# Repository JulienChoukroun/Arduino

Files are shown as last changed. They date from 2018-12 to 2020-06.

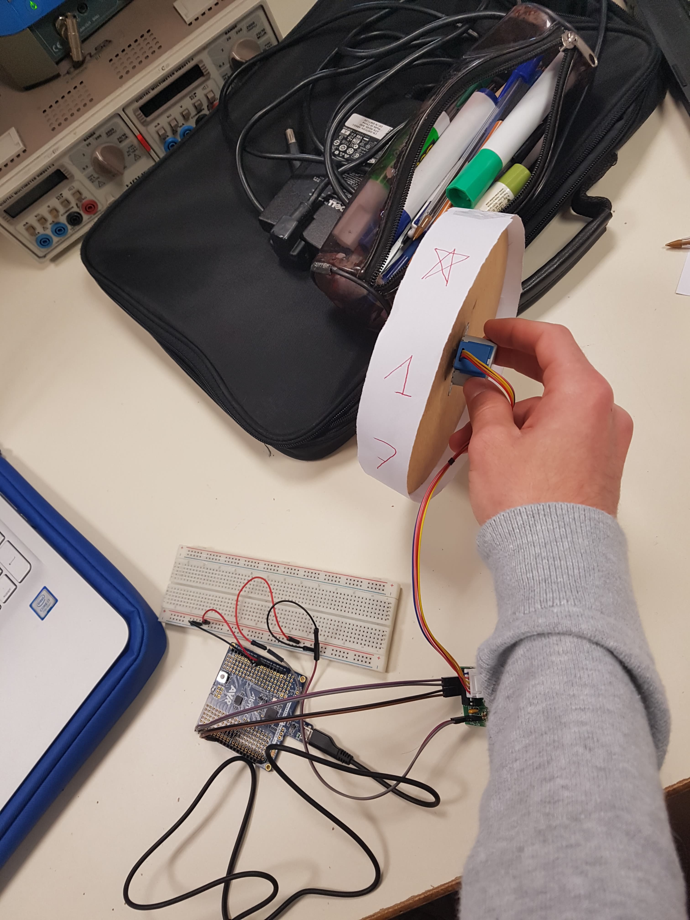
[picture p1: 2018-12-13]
Documentation/Roue/testRoueEnBoisMoteurPasAPas.jpg

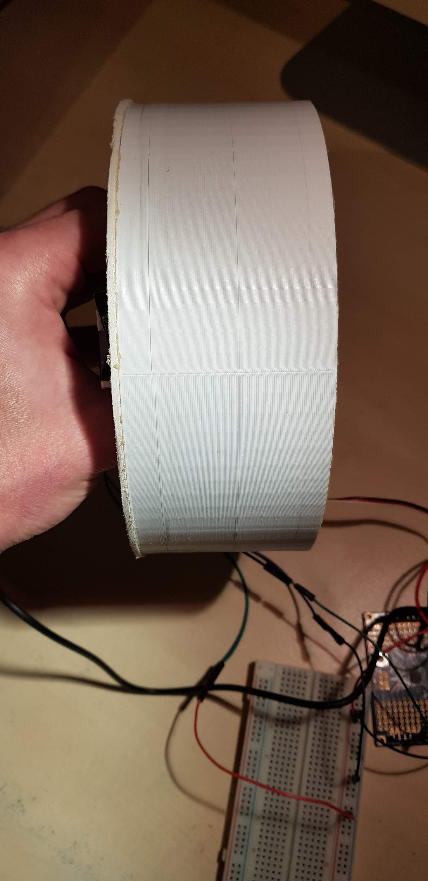
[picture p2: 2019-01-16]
Documentation/Roue/roueAssembléeFace.jpg

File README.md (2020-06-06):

Ce projet est réalisé dans le cadre de la formation de prépa intégrée (deuxième année) de l'Ecole Polytechnique de l'Université Côte d'Azur.
***
# Machine à sous connectée
Machine A Sous
## Présentation
Ce projet a été réalisé avec une carte Arduino Uno.

Nous avons conçu cette machine à sous de A à Z.

Le principe est d'insérer une pièce dans la machine. A ce moment-là, une initialisation va s'effectuer.
Puis, le joueur appuie sur le bouton. Les roues vont alors s'actionnner et s'arrêter aléatoirement. Pour gagner, il faut aligner 3 symboles identiques. 

Liens vidéos finales :

Vidéos aléatoire :
https://www.youtube.com/watch?v=_GDTUbmNEMA

Vidéos jackpot :
https://www.youtube.com/watch?v=zs_Bld9j-1k

https://www.youtube.com/watch?v=MiqmttVf-DY

https://www.youtube.com/watch?v=LnEOkYjUT1s

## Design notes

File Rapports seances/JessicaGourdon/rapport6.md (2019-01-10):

# Séance du 10 Janvier
Aujourd'hui, nous avons trouvé une petite planche en bois fine de 3mm que l'on a fixé au servomoteur. Nous avons ensuite réalisé quelques tests pour observer la rotation de ce dispositif.
Nous avons donc modifier le code du monnayeur. Le nouveau est le suivant: https://github.com/JessicaJulien/projet/blob/master/Codes/monnayeur1.ino
Par la suite nous avons réflechi aux dimensions à prendre pour réaliser les jetons ainsi que l'écart à laisser entre le socle et le cylindre.
Nous avons donc décidé de prendre une épaisseur de 4 mm pour les jetons. Ainsi, nous laissons un écart de 5 mm entre le socle et le cylindre( 1 mm en plus pour éviter tout frottement).
Le schéma du monnayeur est donc le suivant:

<strong> Problème de la roue </strong> <br/>
Nous rencontrons un problème par rapport à la détection de la position initiale de la roue.
Dans un premier temps, nous avons pensé à mettre une petite fente au niveau de chaque autocollant sur la roue et une grande fente à l'endroit où l'on souhaitera que la roue commence à tourner ( la position initiale).
La première fois, la roue tournera lentement pour détecter la position initiale. Une fois la grande fente détectée, la roue s'arrête au niveau de cette position initiale. Ensuite, on fait tourner la roue à sa vitesse normale pendant un certain nombre de secondes tout en comptant le nombre de fentes rencontrées pour pouvoir se repérer.
Puis nous nous sommes rendus compte qu'il serait plus simple de ne réaliser qu'une seule fente, située à la position initiale. Par la suite, grâce à la précision de la vitesse du moteur et à l'aide d'un calcul, nous serons en mesure de connaître la position finale du détecteur.

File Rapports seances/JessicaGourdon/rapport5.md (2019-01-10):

# Travail du 9 Janvier 2019
En réflechissant encore au fonctionnement du monnayeur, je me suis rendue compte que le tube de Smarties, lui non plus, n'était pas assez rigide
pour faire office de cylindre. En effet, étant en carton très fin, il m'aurait fallu le fixer sur le socle en bois avec une tige (en fer ou en bois)
pour le maintenir droit et éviter qu'il ne tombe. J'ai finalement décider de me servir d'un tuyau en PVC qui sera fixé au socle grâce à une petite
équerre. Cela nous permettra également de le surélever de quelques millimètres pour laisser passer un jeton.

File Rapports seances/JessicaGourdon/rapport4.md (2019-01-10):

# Travail du 8 Janvier 2019

Après réflexion, l'idée d'utiliser un rouleau de papier toilette comme cylindre du monnayeur contenant les pièces présente des inconvénients:
il est trop peu rigide et pas assez long. J'ai donc pensé à le remplacer par un gros tube de Smarties.
J'ai réalisé un premier code pour contrôler le servomoteur du monnayeur. Celui-ci est le suivant:
https://github.com/JessicaJulien/projet/blob/master/Codes/premierProgrammeMonnayeur.ino
Le servomoteur, auquel sera fixé une petite plaque de bois, réalisera donc une rotation de 90° de manière à éjecter chaque pièce sortant du cylindre.
Ici, le code a été créé pour éjecter 5 pièces. A l'avenir le nombre de jetons renvoyés dépendra de la valeur indiquée par les roues
(en effet, un 7 nous fera gagner plus de jetons qu'une cerise).

<strong> Le Fablab </strong> <br/>
Avec julien nous nous sommes rendus au Fablab dans le but d'utiliser la découpeuse laser et l'imprimante 3D pour créer les composantes de la première roue.
Face à des problèmes de matériaux non-disponibles et de format des fichiers, nous n'avons pu créer que le socle de la roue. Nous devrons donc y retourner pour créer le reste des composantes ainsi que les jetons.

<strong> Problème à l'avenir </strong> <br/>
Il me reste à trouver un moyen pour faire tenir le tube de Smarties sur le socle en bois tout en laissant un écart entre les deux 
de façon à laisser passer une pièce qui sera éjectée par le servomoteur.

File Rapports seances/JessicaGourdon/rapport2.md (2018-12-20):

# Séance du 20 Décembre 2018

<strong> Test du détecteur IR </strong> <br/>
Pour commencer cette séance, je me suis chargé de tester le détecteur FC-03. Pour cela on se sert de ce détecteur ainsi que d'une LED.
Lorsqu'on passe un objet à l'intérieur de la fourche du détecteur, la LED s'allume. Le code utilisé est:
https://github.com/JessicaJulien/projet/blob/master/Codes/DetecteurIR.ino

Pendant ce temps, Julien réalisait les tests du détecteur HC-SRO4.

<strong> Test du Servomoteur à rotation continue  </strong> <br/>
Au vu des résultats de la semaine dernière, puisque la vitesse du moteur pas à pas ne nous satisfaisait pas, nous choisissons de nous servir du Servomoteur à rotation continue. Nous avons testé ce moteur et la vitesse nous convenait cette fois-ci. 

Nous avons également pris une nouvelle décision pour la réalisation des roues. Au lieu de créer les roues a l'imprimante 3D nous nous servirons de cercles en bois auxquels nous fixons autour une bande en plastique.

Nous devons à présent chercher des autocollants convenant avec les dimensions de la bande en plastique. Nous travaillons également sur le système de détection de chaque image sur la bande en plastique.

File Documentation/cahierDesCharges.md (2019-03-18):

# Cahier des charges

* Contexte : réalisation d’une machine à sous contrôlé par une carte Arduino.
* Objectif :  

  - Détection de l’insertion d’une pièce dans la machine.
  - Rotation des roues et affichage des symboles à la fin du jeu.
  - Rendu de la monnaie si le joueur a gagné.
            
* Contraintes : 

  - Utiliser une carte Arduino.
  - Utiliser une connexion radiofréquence.
  - Délai : 9 séances.

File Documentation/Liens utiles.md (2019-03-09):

#### Arduino Fruit Machine - Feature Reel
<a href="https://www.youtube.com/watch?v=QCF7HrBWTgs&t=0s&index=6&list=LLB7UFHfT3-WoMwWvKr9C8wA">Arduino Fruit Machine - Feature Reel</a>

#### DIY! Slot machine How to make a Casino Slot machine from cardboard
<a href="https://www.youtube.com/watch?v=1jY8ld2u5S0">DIY! Slot machine How to make a Casino Slot machine from cardboard</a>

#### Comment fonctionnent les machines à sous ?
https://www.casino-zen.com/fonctionnement-des-machines-a-sous/

#### Moteurs pas à pas
https://www.gotronic.fr/cat-moteurs-pas-a-pas-1093.htm

#### Servomoteur à rotation continue
https://www.parallax.com/product/900-00025

#### Guide de notre servomoteur à rotation continue
https://www.parallax.com/sites/default/files/downloads/900-00025-High-Speed-CR-Servo-Guide-v1.1.pdf

#### Module MP3
https://www.ebay.fr/itm/YX5300-UART-Control-Serial-MP3-Music-Player-Module-for-Arduino-AVR-ARM-PIC/263548780875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

#### Stickers
https://stickeramoi.com/chiffres-et-numeros/6260-sticker-chiffre-7.html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
https://stickeramoi.com/fuits-legumes-rigolos/11917-sticker-ananas.html
https://stickeramoi.com/sticker-trefle/15005-sticker-trefle-4-feuilles-vert.html
https://stickeramoi.com/fuits-legumes-rigolos/11919-sticker-cerise.html
https://stickeramoi.com/sticker-poker/16929-sticker-poker-carreau-rouge.html
https://stickeramoi.com/sticker-poker/16928-sticker-poker-coeur-rouge.html
https://stickeramoi.com/sticker-poker/8169-autocollant-poker-des-jeu-de-casino.html
https://stickeramoi.com/sticker-poker/16926-sticker-poker-pique-noir.html

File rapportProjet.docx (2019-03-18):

Parcours des Ecoles d’Ingénieurs Polytech (PEIP)

PROJET ARDUINO – PEIP2

Année scolaire 2018-2019

″Polytech’ Slot Machine″

Etudiants : Julien Choukroun et Jessica Gourdon

Encadrants : Mr. Masson et Mr. Abderrahmane

Ecole Polytechnique Universitaire de Nice Sophia-Antipolis, PEIP

1645 route des Lucioles, Parc de Sophia Antipolis, 06410 BIOT

REMERCIEMENTS

Avant d’introduire notre sujet et de rentrer dans les détails de celui-ci, nous tenons à remercier Mr. Masson, professeur d’électronique et directeur du PEIP, pour ses conseils et son aide, ainsi que Mr. Forner, Fabmanager du FabLab de Sophia.

SOMMAIRE

# Introduction

L’univers du casino étant un univers nous touchant particulièrement tous les deux, nous avons choisi de réaliser une machine à sous. Objet connu du grand publique, beau esthétiquement, divertissant et ludique, nous avons conçu cette machine de A à Z.

Ce projet se base sur la carte Arduino Uno.

Le principe est d’insérer une pièce dans la machine. A ce moment-là, une initialisation des roues va s’effectuer : elles vont s’arrêter sur les symboles « 7 ». Ensuite, le joueur appuie sur le bouton pour faire tourner les roues. Ces dernières vont s’arrêter aléatoirement sur des symboles.

Pour gagner, il faut aligner trois symboles identiques. Nous avons mis en place 3 jackpots différents : si nous alignons trois « fruits » (ananas et raisin), nous gagnons 5 pièces. Si nous alignons trois « couleurs » (cœur, carreau, pique et trèfle), nous gagnons 10 pièces. Enfin, si nous alignons trois « 7 », nous gagnons 20 pièces.

Pour commencer, nous allons décrire l’objectif de notre projet ainsi que les composants utilisés. Puis, nous allons donner une vision globale du projet avec les différents modules, accompagnés d’un algorithme, c’est-à-dire, l’enchainement des fonctions de notre programme. Nous allons exposer nos plannings (initial et final), avec une comparaison de ce que nous avons finalement fait. Ensuite, nous allons parler des problèmes que nous avons rencontrés et comment nous les avons surmontés. Pour finir, nous allons expliquer ce qui fonctionne, ce qui ne fonctionne pas et ce qu’il faudrait faire par la suite si nous avions eu encore neuf séances supplémentaires.

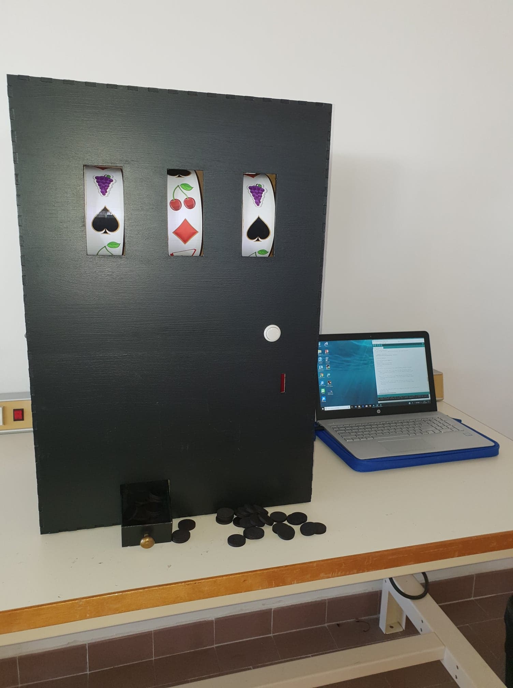
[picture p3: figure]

# Chapitre I : Objectif

## I.1. Cahier des charges

- Contexte : réalisation d’une machine à sous contrôlée par une carte Arduino.
- Objectif : - Détection de l’insertion d’une pièce dans la machine.

- Rotation des roues et affichage des symboles à la fin du jeu.

- Rendu de la monnaie si le joueur a gagné.

- Contraintes : - Utiliser une carte Arduino.

- Utiliser une connexion radiofréquence.

- Délai : 9 séances.

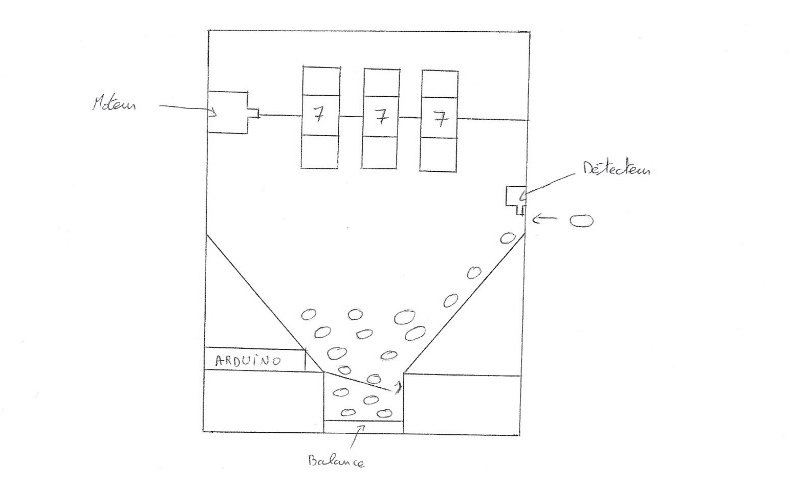
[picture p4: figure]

Figure I.1. Dessin du prototype de machine à sous.

## I.2. Composants utilisés

Pour réaliser la Polytech’ Slot Machine, il nous a fallu de nombreux outils et différents composants.

- Il nous a évidemment fallu utiliser une carte Arduino. Nous avons choisi la carte Arduino Uno.

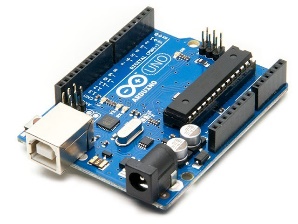
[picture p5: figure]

Figure I.2. Carte Arduino Uno.

- Nous nous sommes également servis de trois servomoteurs à rotation continue pour réaliser les rotations des trois roues. En effet, ceux-ci nous offraient une vitesse de rotation satisfaisante ainsi qu'un bon contrôle de celles-ci.

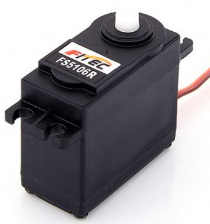
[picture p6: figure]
RÃ©sultat de recherche d'images pour "servomoteur rotation continue arduino"

Figure I.3. Servomoteur à rotation continue.

- Il nous a ensuite fallu un servomoteur à rotation 180° pour réaliser le rendu de la monnaie. En effet, celui-ci nous a permis d’éjecter les pièces, à partir du monnayeur.

Figure I.4. Servomoteur à rotation 180°.

- Puis, nous avons eu besoin de quatre détecteurs Keyes IR-01.

Il s'agit d'un module possédant une diode Infrarouge (IR) ainsi qu'un phototransistor. La détection se réalise grâce à une comparaison de tension. En présence de lumière le phototransistor est passant. La tension de sortie sera égale à 0 V (« 0 » en valeur logique). Il s'agit donc de l'état pour lequel le module ne détecte rien. S'il n'y a pas de lumière, le phototransistor est bloqué. La tension de sortie sera donc égale à 5 V (« 1 » en valeur logique). Il s'agit donc de l'état pour lequel le module détecte quelque chose. Nous avons donc besoin d'une surface noire (qui ne laisse pas passer la lumière) pour la détection.

Nous avons utilisé trois de ces modules pour les roues et le quatrième pour la détection des pièces lors de leur insertion.

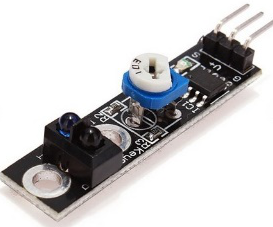
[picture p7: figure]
RÃ©sultat de recherche d'images pour "keyes ir 01 arduino"

Figure I.5. Détecteur Keyes IR-01.

- Nous nous sommes également servis d'un gros bouton poussoir qui déclenchera la rotation des roues.

Figure I.6. Bouton poussoir.

- Nous avons aussi utilisé des bandes de LED pour le système d'éclairage des roues.

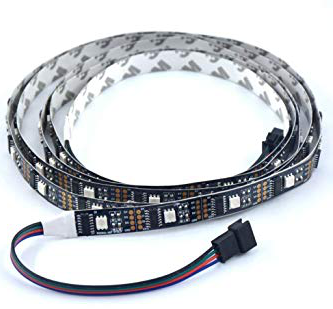
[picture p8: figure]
RÃ©sultat de recherche d'images pour "bande led arduino"

Figure I.7. Bande de LED.

- Il nous a aussi fallu utiliser un module MP3 pour le système de musique pendant le jeu.

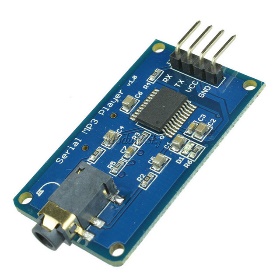
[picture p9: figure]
Une image contenant équipement électronique, circuit Description générée avec un niveau de confiance très élevé

Figure I.8. Module MP3.

- Enfin, nous nous sommes servis d'un module Bluetooth pour renvoyer l'information concernant notre victoire ou notre échec sur notre smartphone. Par exemple : « Vous avez gagné 20 pièces ! » ou « Perdu ! Vous n’avez rien gagné ! ».

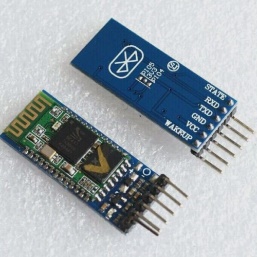
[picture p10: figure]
RÃ©sultat de recherche d'images pour "module bluetooth hc05"

Figure I.9. Module Bluetooth.

# Chapitre II : Principaux modules

## II.1. Initialisation des roues

Une étape importante de notre projet a été l'élaboration du système d'insertion des pièces et d'initialisation des roues.

Sur la paroi avant de notre machine à sous se trouve une encoche à travers laquelle les pièces sont insérées. Nous avons ensuite créé une boite en carton possédant elle aussi une encoche, alignée à la première. Cette boîte nous sert de bac récupérateur afin de stocker les pièces à la suite de leur insertion. Nous avons ensuite fixé le détecteur Keyes-01 sur une paroi du bac. Le principe est que ce module détecte les pièces lors de leur insertion. Or, il s'agit d'un module sensible à la lumière (détectant donc les objets qui ne réfléchissent pas celle-ci). C'est pour cette raison que nos pièces sont toutes peintes en noire.

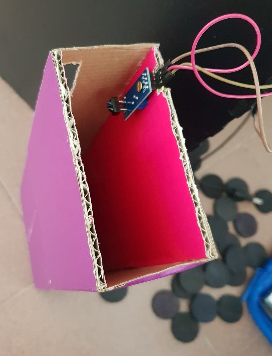
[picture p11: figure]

Figure II.1. Insertion des pièces.

Le principe de fonctionnement est le suivant : lors de la détection d'une pièce, les roues s'initialisent. L'initialisation est le fait de forcer les roues à afficher le même symbole avant de lancer le véritable jeu. Cela permet de les faire toutes partir de la même position, et ainsi de pouvoir les contrôler. Nous avons choisi comme position initiale le symbole « 7 ». C'est pour cela qu'un scotch noir, détectable par le module Keyes de chaque roue, est fixé au niveau de ce symbole. Lors de la détection de la pièce, les roues vont alors chacune se lancer. Elles vont réaliser un seul tour à vitesse lente avant de s'arrêter sur le symbole « 7 ». Tant que le module de chaque roue ne détecte pas le scotch noir, celles-ci continuent de tourner. Il a fallu alors contourner le problème suivant : à l'insertion d'une pièce, les roues commençaient à tourner mais ne s'arrêtaient jamais. Nous avons donc créé une variable, dans le code, pour remédier à cela. En effet, lorsque la pièce est détectée par le module du bac, on affecte la valeur « 1 » à notre variable. Puis, si cette valeur est à « 1 », alors on lance l'initialisation. Il faut bien entendu remettre cette variable à « 0 » à la fin de notre boucle. Grâce à cela, tout fonctionne parfaitement.

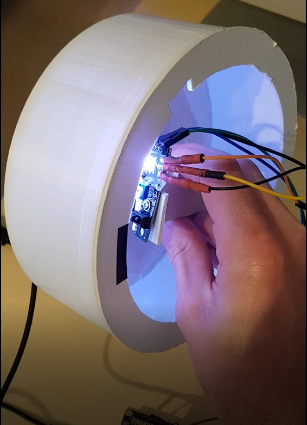
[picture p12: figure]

Figure II.2. Initialisation d’une roue.

## II.2. Conception des roues

### II.2.1. Prototype d’une roue

Initialement, nous souhaitions utiliser un moteur pas à pas pour la rotation de chaque roue. Pour réaliser les premiers tests, nous avons donc créé un prototype d'une roue. Pour cela, nous nous sommes servis d'un socle en bois auquel nous avons fixé le moteur pas à pas. Ce socle était entouré d'une bande de papier. Notre but était de savoir si ce moteur permettait à la roue de tourner aussi vite que nous l'attendions. Finalement, la vitesse n'était pas suffisante.

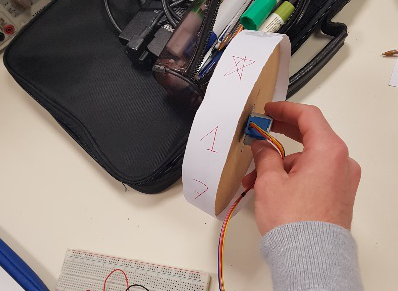
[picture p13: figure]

Figure II.3. Roue avec moteur pas à pas.

Nous avons donc cherché un autre moteur permettant à la roue d'avoir une vitesse plus élevée. Nous avons alors utilisé un servomoteur à rotation continue. La bande de papier utilisée autour du socle a ensuite été remplacée par une bande en plastique plus large et plus solide.

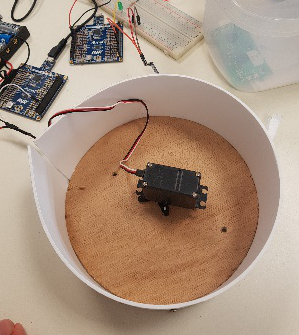
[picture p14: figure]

Figure II.4. Roue avec servomoteur à rotation continue.

Nous avons ensuite mis en place un détecteur sur la roue afin de connaitre la valeur des symboles que celle-ci affichera à la fin du jeu. Initialement, nous voulions réaliser une encoche alignée sur chaque symbole de la roue pour la détection. Ainsi, nous avons utilisé un module avec une fourche optique. Puis, nous nous sommes rendu compte qu'une seule fente suffirait. En effet, celle-ci se placerait au niveau du symbole "7" représentant la position initiale. Ainsi, en comptant le nombre de fois où la fente est détectée par le module et en calculant le temps pour effectuer une rotation, il nous ait possible de repérer la position finale et ainsi de pouvoir contrôler la roue.

Figure II.5. Détecteur avec fourche optique.

Nous nous sommes rendus au FabLab de Sophia dans le but de faire évoluer notre prototype en un véritable objet.

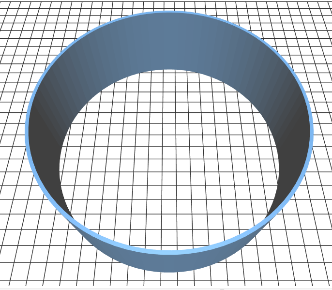
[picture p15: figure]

Figure II.6. Modélisation de la roue en 3D.

### II.2.2. Réalisation des roues

Après l'assemblage de la roue, nous nous sommes concentrés sur le code permettant de contrôler celle-ci. Il y a d'abord l'initialisation durant laquelle la roue tourne jusqu'au moment où le capteur atteint la fente.

Notre objectif était de faire tourner la roue pendant un certain nombre de secondes avant qu'elle se fige à une certaine position. On déterminerait celle-ci grâce à un calcul prenant en compte le temps nécessaire pour faire un tour complet. Nous avons donc mesuré ce temps.

Puis, une nouvelle idée nous est venue. Il s'agit de faire tourner 10 fois la roue dans un premier temps. Dans un deuxième temps, on tirerait un nombre aléatoire qui déciderait de la position finale (position adoptée pendant le onzième et dernier tour de roue). Cependant, nous avons eu un problème de vitesse. En effet, pour réaliser un tour complet, notre roue mettait 390 millisecondes (ms). Mais pour lui faire réaliser 10 tours complets celle-ci mettait 460 ms par tour. Nous avons alors vu que cela était dû aux frottements exercés par le détecteur. Pour contourner ce problème, nous avons testé un nouveau capteur : le Keyes IR-01. A la place de la fente, nous plaçons donc un scotch noir détectable par ce module. Grâce à cela, il n'y a plus aucun frottement.

Pour éclairer nos roues, nous avons utilisé une bande de LED fixé au même endroit que le détecteur.

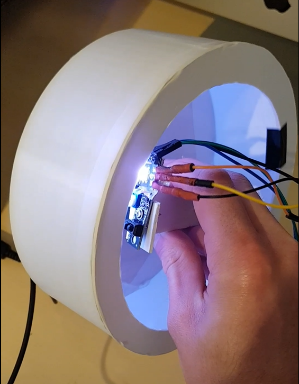
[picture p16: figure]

Figure II.7. Roue avec nouveau détecteur et lumière.

Au vu des résultats sur la première roue, nous avons conçu les deux autres. Il a fallu ensuite fixer l'ensemble sur un support en bois grâce à des pinces qui vont venir s'accrocher aux roues.

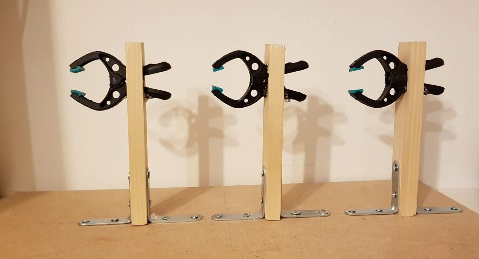
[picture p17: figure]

Figure II.8. Support de fixations des roues.

Puis nous avons collé les autocollants représentant les symboles sur celles-ci. Une nouvelle idée nous est alors venue. Après avoir fait tourner les roues 10 fois, à la place de prendre un nombre aléatoire décidant de la position finale, il serait préférable de créer une liste de nombres, pour chaque roue, correspondant à la position du centre de chaque autocollant. On tirera alors aléatoirement un nombre parmi cette liste pour décider de la position finale de chaque roue. Cela permettra d'éviter que la position finale se situe entre deux autocollants. Pour effectuer ce travail, nous nous sommes servis du temps nécessaire à chaque roue pour effectuer un tour. Après calculs, nous avons donc associé chaque autocollant à un nombre.

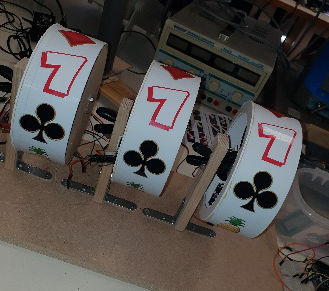
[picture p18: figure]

Figure II.9. Roues avec autocollants.

## II.3. Rendu de la monnaie

Pour notre machine à sous, il fallait élaborer un mécanisme permettant de rendre les pièces en cas de victoire.

Pour ce monnayeur, nous avions besoin d'un cylindre. L'utilisation de rouleaux de papiers toilettes pour réaliser celui-ci était une idée. Les pièces seraient alors empilées dans ce cylindre. En bas de celui-ci se trouverait une ouverture laissant passer la dernière pièce, posé sur une plaque en bois. Nous nous servirions d'un servomoteur à rotation 180° auquel serait fixé une plaque en bois pour pousser chaque pièce une par une dans le bac. Ainsi, nous pourrions être en mesure de contrôler le nombre de pièces rendues.

Après réflexion, l'idée d'utiliser un rouleau de papier toilette comme cylindre contenant les pièces présentait des inconvénients : il était trop peu rigide et pas assez long. Nous avons donc pensé à le remplacer par un gros tube de Smarties.

Il a fallu réaliser un premier code pour contrôler le servomoteur du monnayeur. Celui-ci, fixé à une petite plaque de bois, réalise donc une rotation de 90° de manière à éjecter chaque pièce sortant du cylindre. Le nombre de pièces renvoyées dépend alors du symbole final indiqué par les roues (en effet, un « 7 » nous fera gagner plus de pièces qu'une « cerise »).

Il restait à trouver un moyen pour faire tenir le tube de Smarties sur le socle en bois tout en laissant un écart entre les deux de façon à laisser passer une pièce qui sera éjectée par la suite. En y réfléchissant encore nous nous sommes rendu compte que le tube de Smarties, lui non plus, n'était pas assez rigide pour faire office de cylindre. Nous avons finalement décidé de nous servir d'un tuyau en PVC qui serait fixé au socle grâce à des équerres. Cela nous a permis également de le surélever de quelques millimètres pour laisser passer une pièce.

Par la suite, nous avons réfléchi aux dimensions à prendre pour réaliser les pièces ainsi que l'écart à laisser entre le socle et le cylindre. Nous avons donc choisi une épaisseur de 4 millimètres (mm) pour les pièces. Ainsi, nous laissons un écart de 5 mm entre le socle et le cylindre (1 mm en plus pour éviter tout frottement). Le moteur est fixé sur une planche en bois qui est surélevée pour qu'il ne s'abime pas. Nous avons rallongé le morceau de bois servant à pousser les jetons. En effet, avec le morceau de bois initial les pièces restaient bloquées. Nous avons donc utilisé une planche en plastique beaucoup plus longue et de forme arrondie pour qu'elle ne se bloque pas dans les équerres. L'avantage du plastique est que celui-ci est souple. Cela nous a arrangé puisque le morceau de bois initial n'était pas droit. Ici, l'aile en plastique, se sert du socle du cylindre comme appui pour pousser les pièces.

Nous avons ensuite réalisé le code final pour le monnayeur c'est-à-dire le code nous renvoyant le bon nombre de pièces selon les symboles obtenues. Enfin, nous avons créé un tiroir dans lequel le monnayeur fait tomber les pièces à la sortie.

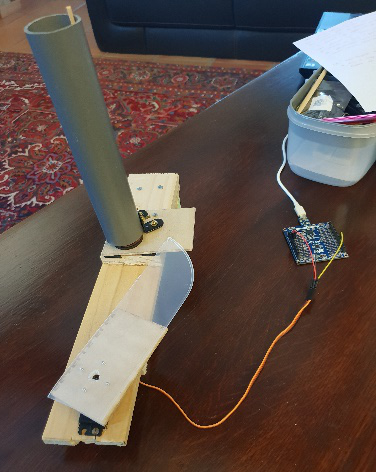
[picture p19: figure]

Figure II.10. Monnayeur.

# Chapitre III : Réalisation

## III.1. Algorithme de fonctionnement

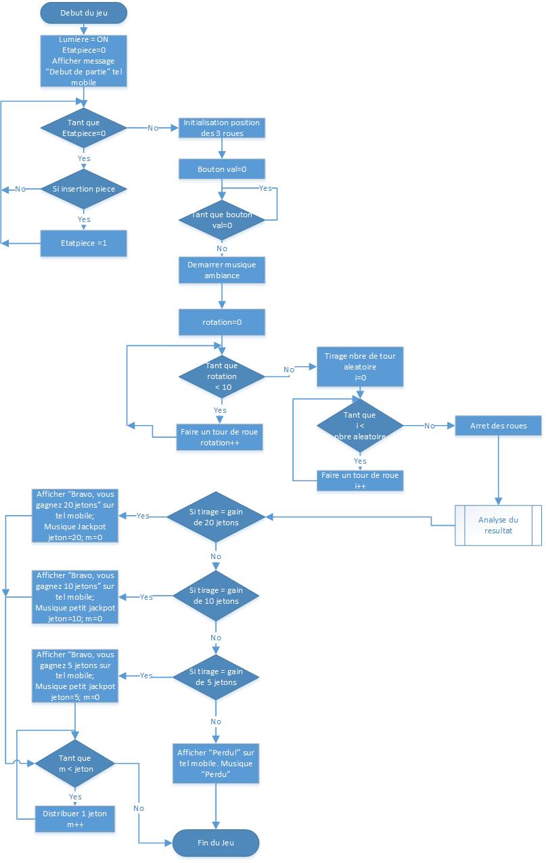
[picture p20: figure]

Figure III.1. Algorithme-logigramme de fonctionnement.

## III.2. Evolution du planning

La démarche de création de la Polytech' Slot Machine a évolué au vu des premiers objectifs que nous nous étions fixés.

Initialement, nos roues devaient fonctionner à l'aide d'un moteur pas à pas. Néanmoins, comme nous l'avons expliqué précédemment, nous nous sommes finalement servis de servomoteurs à rotation continue.

Le premier gros travail de notre projet fut la conception d'un prototype d'une roue. Puis, il y eut, en parallèle la conception de monnayeur ainsi que de la première véritable roue. Ces étapes importantes de la réalisation de notre machine à sous ont été détaillés dans le chapitre II de notre rapport.

Nous avons ensuite créé les deux autres roues à l'image de la première. Il a, par la suite, été nécessaire de faire fonctionner l'ensemble contenant les trois roues ainsi que le système de rendu de la monnaie.

Nous nous sommes ensuite attelés à la réalisation de la boite. Nous avons réalisé, grâce à un logiciel les modélisations nécessaires pour la création de cette structure. La découpeuse laser du FabLab de Sophia étant de trop petite taille, nous avons été contraints d'avoir recours à celle du CastoLab du magasin Castorama. En effet, notre structure mesurait 75 cm de hauteur alors que la découpeuse laser du FabLab n'est manipulable que sur des objets ne dépassant pas 61 cm de hauteur. Nous avons par la suite réalisé le montage de la boîte. Il a fallu créer une porte à l'arrière pour recharger le monnayeur ou pour être en mesure de changer certains modules en cas de dysfonctionnement.

Nous avons ensuite créé le système permettant de lancer nos roues à pleine puissance c'est-à-dire l'élément déclencheur du jeu. Initialement, nous avions pour but de créer un bras placé sur le côté de la machine. Néanmoins, nous nous sommes rendu compte que, de nos jours, la majeure partie des machines à sous présentes dans les casinos ne possédaient plus de bras. Celui-ci ayant été remplacé par un bouton. Nous avons également réfléchi au fait que la mise en place d'un bras dépassant de la structure rendrait notre machine fragile. En effet, à chaque déplacement de la boîte, le bras risquerait de s'abimer et ainsi de dysfonctionner. Au vu de cela, nous avons pris la décision de mettre en place un bouton qui lancerait le jeu.

Puis, nous avons finalisé l'insertion des roues. Pour cela, nous avons mis en place le dispositif de détection lors de l'insertion des pièces. Cette étape est détaillée dans le chapitre II.

Une fois ce travail réalisé, nous avions à travailler la communication Bluetooth de notre projet. Nous nous sommes donc servis d'un module Bluetooth HC-06. Le principe est qu'à la fin du jeu, le joueur reçoit sur son téléphone un message l'informant s'il a gagné ou perdu. En cas de victoire, il nous informe également du nombre de pièces remportées.

Enfin, nous avons mis en place un système de musique grâce à un module MP3. Pour cela, nous avons cherché des sons en rapport avec l'univers du casino. Nous les avons ensuite modifiés grâce au logiciel Audacity. Parmi les quatre musiques créées, il y aura une musique d'ambiance. En effet, celle-ci se déclenche lorsque l'on appuie sur le bouton et s'arrête lorsque les roues atteignent leur position finale. Puis, parmi les trois autres musiques, deux seront déclenchés lorsque l'on gagne. Une d'entre elles est dédiée aux gros jackpots (les trois « 7 ») et l'autre est dédiée aux plus petits jackpots. Enfin, la dernière musique retentit lorsque l'on perd.

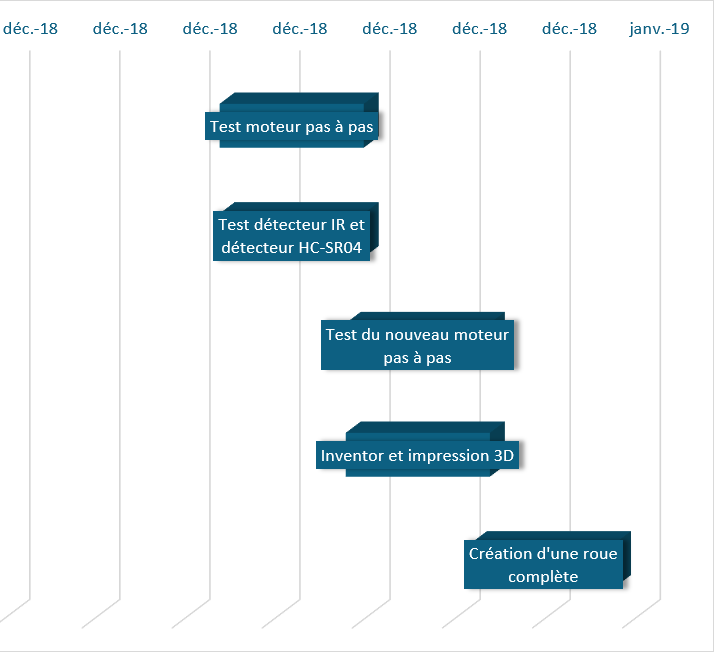
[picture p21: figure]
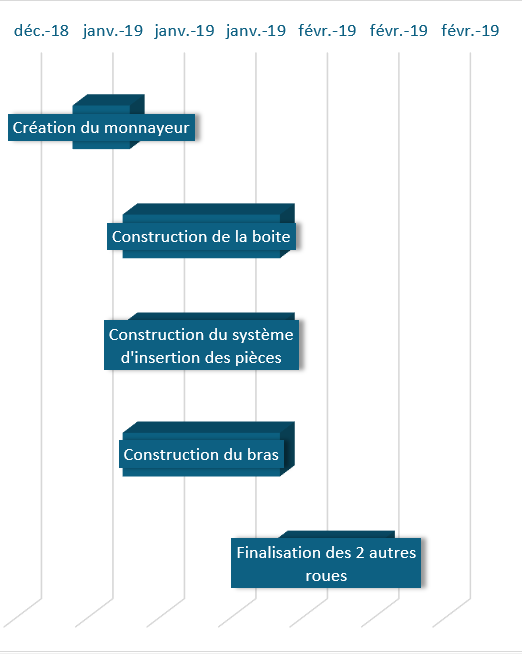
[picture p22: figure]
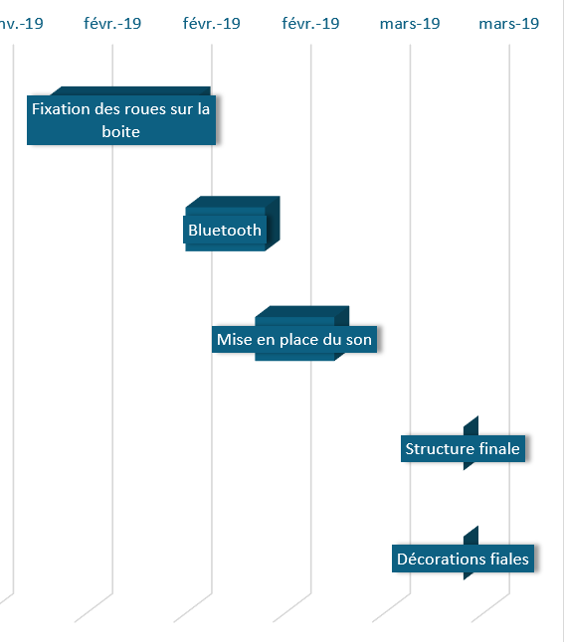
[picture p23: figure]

Figure III.2. Planning initial.

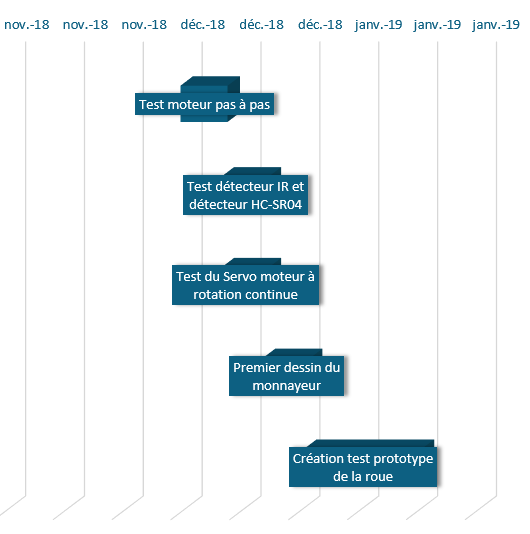
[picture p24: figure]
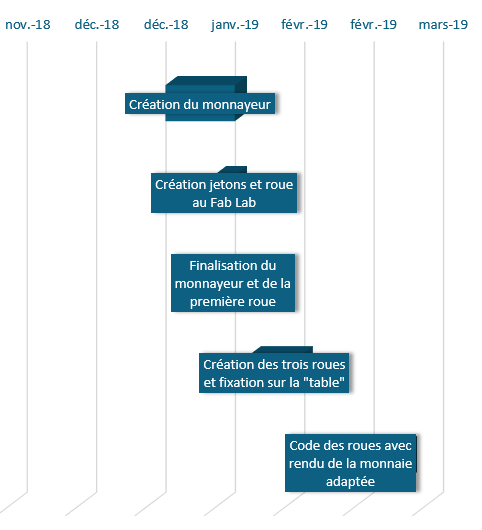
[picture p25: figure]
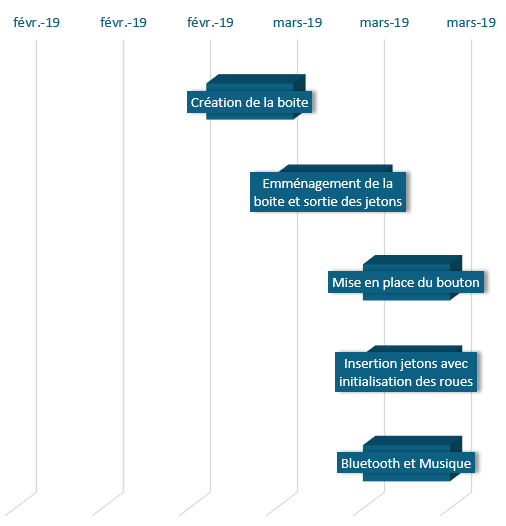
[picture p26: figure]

Figure III.3. Planning final.

## III.3. Problèmes rencontrés

Tout au long de ce projet, nous avons rencontré certains problèmes. Nous avons tout de même réussi à les surmonter.

Tout d’abord, la première fois que nous avons tenté de connecter le monnayeur à nos roues, nous avons soudainement eu un problème avec celui-ci alors qu’il fonctionnait parfaitement auparavant. Nous avons donc changé de moteur et refait les câblages, mais cela ne fonctionnait toujours pas. Nous nous sommes alors rendu compte que le problème était dû à un câble défaillant.

Un autre problème est survenu. Lorsque nous avons connecté les 4 servomoteurs sur la carte (les trois roues et le monnayeur), nos roues tournaient beaucoup trop longtemps avant de s’arrêter. Pour remédier à cela, nous avons placé un condensateur.

Puis, lorsque nous nous sommes occupés du tirage d’un nombre aléatoire dans notre code, nous avons rencontré un problème. Nous avons, tout d’abord, utilisé la fonction « random() » qui permet de faire tourner la roue aléatoirement. Cependant, à chaque exécution de notre programme, nous avions toujours la même série de nombres qui sortait. Puis, nous avons trouvé sur internet comment résoudre ce problème : grâce à la fonction « randomSeed() ». En effet, la fonction « random() » est une fonction mathématique qui génère une très longue suite de nombres. Cependant, il y a un moment où cette suite se répète. Et lorsque nous n'utilisions pas la fonction « randomSeed() », à chaque exécution, la suite revenait au début. De cette manière, nous avions toujours les mêmes nombres « aléatoires ». Donc, la fonction « randomSeed() » permet de faire démarrer la suite de nombre à un endroit arbitraire. Grâce à cela, nous avons l'impression d'avoir des nombres complètement aléatoires.

Un autre problème a été notre difficulté à contrôler les positions des trois roues en même temps, alors que séparément tout fonctionnait parfaitement bien. En effet, lorsque nous faisons tourner nos trois roues en même temps, la deuxième roue se lance quelques millisecondes après la première. De même, la troisième roue se lance quelques millisecondes après la deuxième. Ainsi, les trois roues ne se lançaient pas en même temps (à quelques millisecondes près). Ce qui fait que nous ne pouvions pas avoir 3 symboles identiques en sortie. Pour résoudre ce problème, lorsque nous appuyions sur le bouton, nous actionnons les roues à vitesse lente, grâce à la fonction « delay() », le temps que nos trois roues se synchronisent. Ainsi, nous arrivons à faire partir nos trois roues exactement en même temps.

# Conclusion

Après ces neuf séances de travail, notre cahier des charges a pratiquement été satisfait. Nous avons réussi à détecter l’insertion d’une pièce dans la machine, ainsi qu’à actionner les roues lorsque le joueur appuie sur le bouton et à rendre la monnaie en cas de victoire. Nous sommes également parvenus à ajouter à cette machine de la musique pour la rendre plus divertissante ainsi que de la lumière dans le but qu’elle soit plus attractive visuellement. Enfin, nous avons respecté la contrainte de la communication radiofréquence.

Ainsi, tous les objectifs ont été atteint. Néanmoins, un problème persiste. Lorsque nous branchons notre alimentation à différents endroits, les vitesses de rotation des roues varient. Cela crée alors un décalage entre les valeurs attendues et les valeurs obtenues. Il est donc difficile d’obtenir une rotation parfaite des roues et, par conséquent, un arrêt parfait sur les symboles.

Si nous avions eu encore neuf séances, nous aurions souhaité améliorer l’algorithme de rotation des roues. En effet, il aurait été appréciable de se servir de probabilités, à l’image des machines à sous présentes dans les casinos, au lieu de se fier uniquement à l’aléatoire. L’autre objectif majoritaire si nous avions eu du temps supplémentaire aurait été d’avoir un meilleur contrôle des roues quel que soit l’endroit.

# Bibliographie

- Chaîne YouTube du projet : https://www.youtube.com/channel/UCKHqffYvU7zbKjJOJ80EV1w
- Notre servomoteur à rotation continue :

https://www.parallax.com/sites/default/files/downloads/900-00025-High-Speed-CR-Servo-Guide-v1.1.pdf

- Fonctionnent d’une machine à sous :

https://www.casino-zen.com/fonctionnement-des-machines-a-sous/

- Vidéo démontage d’une machine à sous :

https://www.youtube.com/watch?v=QCF7HrBWTgs&t=0s&index=6&list=LLB7UFHfT3-WoMwWvKr9C8wA

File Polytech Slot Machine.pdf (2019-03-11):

# Polytech’ Slot Machine


Projet Arduino 2018/2019

Jessica GOURDON

Julien CHOUKROUN

# Sommaire

- Motivations et présentation du projet
- Présentation du matériel
- Initialisation des roues
- Contrôle des roues
- Rendu de la monnaie
- Constitution de la boîte
- Evolution du planning
- Conclusion

# Motivations et présentation du projet


# Présentation du matériel


Servo moteur à
rotation continue


Servo moteur à
rotation 180°


Gros bouton
poussoir


Bande de LED


Détecteur Keyes
IR-01

Module Bluetooth


Module MP3

# Initialisation des roues


# Contrôle des roues


# Rendu de la monnaie


# Constitution de la boîte


# Evolution du planning (1)


# Evolution du planning (2)


# Conclusion


- Apprendre par soit-même
- Approfondir ses connaissances
- Travail d’équipe
- Rigueur
- Autonomie

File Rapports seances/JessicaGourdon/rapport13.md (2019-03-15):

# Travail du 6 Mars
Pendant que Julien continuait de travailler sur les roues, je me suis occupée de l'insertion des jetons. J'ai donc fixé un détecteur FC-03
sur la paroi du bac récupérateur de jetons. Nous avons ensuite écrit  le code de façon à déclencher l'initialisation des roues lorsque 
l'on insère un jeton. Nous avons alors eu un problème. Les roues qui, pendant l'initialisation, étaient censés réaliser seulement un tour avant de s'arrêter sur les trois 7, ne s'arretaient plus du tout.

# Travail du 7 Mars
Aujourd'hui nous avons réglé le problème de l'initialisation. En effet, au lieu de simplement mettre un "if" qui verifiait la condition "Etat du detecteur de jeton à 1" avant de lancer l'initialisation, nous avons créé une nouvelle variable.
Si l'état du détecteur de jetons est à 1, la variable prend la valeur 1. Et si cette variable est à 1, alors on lance l'initialisation des roues.
A la fin de celle-ci, on remet notre variable à 0. Grâce  cela notre initialisation marche très bien. Ensuite, nous avons mis en place le module Bluetooth.
L'objectif est que l'on puisse avoir sur notre smartphone un message nous informant si l'on a gagné et combien de jetons on a gagné dans ce cas.
Nous avons réussi à réaliser cela.

# Travail du 8 Mars
Aujourd'hui nous avons mis en place le système de musique avec un module MP3.
A l'aide du logiciel Audacity nous avons modifié un son. En effet, nous souhaitions mettre une musique d'ambiance pendant que 
les roues tournaient. Nous avons donc rallongé un son trouvé sur internet pour qu'il dure 10 secondes (durée pendant laquelle les roues tournent vite).
Nous avons ensuite mis une musique lorsque l'on gagne le grand Jackpot (les trois 7). Puis nous avons mis une autre musique lorsque l'on obtient trois figures identiques (autre que les trois sept).
Enfin, nous avons mis un son en cas de défaite. Tout marche très bien à présent.

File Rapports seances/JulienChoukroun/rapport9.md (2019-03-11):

# Avant cette séance

* Avec Jessica, on a ajouté le bouton à notre programme. Pour ce faire, on a rajouté une condition : si on appuie sur le bouton, les roues tournent.
* Puis, on a ajouté le détecteur de pièce (Keyes-01). Le principe est maintenant de passer une pièce devant ce détecteur, puis de faire l'initialisation des roues, enfin d'appuier sur le bouton et faire tourner les roues. On a donc rajouté une condition : si la pièce passe devant le détecteur, on fait l'initialisation des roues. Mais on a rencontré un problème à ce niveau là. En effet, lorsqu'on insérait une pièce, l'initialisation commençait normalement mais ne s'arrêtait jamais. C'est-à-dire que les roues ne s'arrêtaient pas, alors qu'elles étaient cencées tourner au maximum un seul tour, jusqu'à s'arrêter sur les trois "7". En cherchant sur Internet et en testant plusieurs codes, on est arrivé à régler ce problème : dans notre condition qui nous posait problème, on a inséré une nouvelle variable. Ainsi, si on passe la pièce devant le détecteur, on affecte la variable à 1. Et lorsque cette variable est à 1, on peut alors lancer l'initialisation, enfin on remet cette variable à 0. Maintenant, cela fonctionne très bien.
* On a inséré un module bluetooth à notre machine. Le principe est qu'à la fin du jeu, le joueur reçoit sur son téléphone un message l'informant s'il a gagné avec combien de jetons rapportés ou s'il a perdu. Cela fonctionne bien.
* On a mis en place un système de musique grâce à un module MP3. J'ai cherché des sons et musiques en rapport avec les machines à sous. Au final, j'en ai trouvé 4. Je les ai donc téléchargés et modifiés légèrement sur le logiciel Audacity. Parmi ces 4 musiques, il va y avoir une musique d'ambiance dès qu'on appuie sur le bouton jusqu'à l'arrêt complet des roues. Les 3 autres musiques viennent après cette musique là. Parmi les 3 musiques, 2 musiques vont être pour les jackpots : une musique pour le "gros" jackpot (les trois "7") et l'autre musique pour les 2 autres jackpots. Enfin la dernière musique sera la musique si on perd.
* Voici le programme final : https://github.com/JessicaJulien/projet/blob/master/Codes/machineASous.ino
Et voici un programme qui permet d'avoir les jackpots (sans l'aléatoire) : https://github.com/JessicaJulien/projet/blob/master/Codes/machineASousTruque.ino
* Notre projet est maintenant terminé. Comme nous avons pas pu filmer en salle de cours, j'ai filmé à la maison. 

Voici 3 démonstrations de la machine à sous.

Gros jackpot "7" 20 jetons :
<a href="https://www.youtube.com/watch?v=zs_Bld9j-1k">Machine A Sous : Gros Jackpot '7' 20 jetons</a>

Petit jackpot "Ananas" 5 jetons :
<a href="https://www.youtube.com/watch?v=7xNCxAcZ2dk">Machine A Sous : Petit Jackpot 'Ananas' 5 jetons</a>

Perdu :
<a href="https://www.youtube.com/watch?v=_GDTUbmNEMA">Machine A Sous : Perdu</a>

Remarque : lorsqu'on branche notre alimentation à différents endroits, la rotation des roues est légèrement modifiée. Ce qui fait que dans les vidéos (prises à la maison), les trois symboles ne sont pas tout à fait alignés, alors qu'en salle de cours elle le sont très bien. On essayera donc de prendre de meilleures vidéos.

# Séance du 12 Mars 2019

* Derniers réglages de la rotation des roues avant l'oral.

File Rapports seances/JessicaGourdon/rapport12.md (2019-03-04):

# Week-end du 3 Mars
Durant ce week-end je me suis occupé de monter la boite. J'ai collé les bords et j'ai peint en noir l'exterieur. Je me suis également occupé de la porte  l'arrière. Pour cela,
j'ai mis des charnières, un bouton pour l'ouverture ainsi que des crochets pour éviter que la porte ne vienne endommager le matériel à l'intérieur de la boite.
Je me suis également charger de mettre des poignées pour faciliter le transport. 

J'ai ensuite travaillé sur le dispositif de sortie des jetons. J'ai donc abandonné mon idée de "tobogan" à jeton. A présent il y a 
un petit tiroir dans lequel le monnayeur fait tomber les jetons à la sortie. On peut le voir ici :

Je me suis ensuite occupé de l'insertion des jetons. J'ai donc créé une boite possédant une encoche à travers laquel ceux-ci seront insérés.


# Séance du 04 Mars 2019
Durant cette séance, avec Julien nous avons dans un premier temps travaillé uniquement sur les roues. Nous avons donc fait des réglages 
par rapport au delay() puisque les troies roues ne se lancent pas en même temps. Grâce à cela, nous avons permis aux trois roues de pouvoir
commencer à tourner en même temps. On a donc réussi à obtenir trois symboles identiques.<br/>
Nous avons ensuite réalisé les mesures du temps nécessaire pour obtenir chaque symbole. Ces mesures nous seront utiles pour créer notre liste à
partir de laquelle on tirera notre nombre aléatoire qui décidera de la position de chaque roue. Nous avons donc adapté le code du monnayeur 
avec ces nouvelles données. Le code est celui-ci: https://github.com/JessicaJulien/projet/blob/master/Codes/rouesMonnayeurTriche.ino
<br/>
Puis, nous avons decidé de connecter les roues et le monnayeur ensemble. Nous avons alors eu un problème. Le monnayeur, qui a toujours très bien fonctionné
jusque là, ne fonctionnait plus. On a donc changé de moteur. Cependant, il ne fonctionnait toujours pas après cela. Nous avons donc découvert que le problème 
provenait de câbles abimés. A présent, le monnayeur fonctionne à nouveau.
<br/>
Néanmoins, un problème subsiste. Selon l'endroit où l'alimentation est branchée le temps de rotation des roues est modifié. Les valeurs de temps que l'on mesure sont donc 
elles aussi modifiées. Il en résulte que l'alignement des symbôles en fin de rotation est compromis.<br/>
Voici une photo de la boite finale:


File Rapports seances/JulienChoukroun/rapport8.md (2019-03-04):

# Séance du 04 Mars 2019

* Au cours de cette séance, Jessica et moi avons résolu le problème de contrôle des 3 roues en même temps, afin d'avoir 3 symboles identiques en sortie. Mais on a résolu cela en utilisant des delay() lors de notre setup(). En effet, lorsqu'on fait tourner nos 3 roues en même temps, la 2ème roue se lance quelques milisecondes après la 1ère et la 3ème roue se lance quelques milisecondes apres la 2ème. Ainsi, les 3 roues ne se lançaient pas en même temps (à quelques milisecondes près). Ce qui fait qu'on ne pouvait pas avoir 3 symboles identiques en sortie. Donc grâce au delay(), on retarde la rotation de la roue. Cela permet aux 3 roues de s'actionner en même temps. Et donc d'avoir 3 symboles identiques en sortie à la fin de la rotation.
* Après avoir résolu ce problème, on a mesurer le temps que mettent les roues pour atteindre chaque symbole (8 symboles). On a donc 8 temps différents. Avec ces 8 temps, on a paramétré les différents jackpots (3 jackpots). Voici le code qui résume tout ce qu'on a modifié (code sans l'aléatoire) : https://github.com/JessicaJulien/projet/blob/master/Codes/rouesMonnayeurTriche.ino
* Lorsqu'on a voulu connecter le monnayeur à nos roues, on a soudainement eu un problème car notre monnayeur fonctionnait parfaitement auparavant. On a donc changé de moteur et refait les cablâges, mais cela ne fonctionnait toujours pas. Mais on s'est rendu compte que le problème était dû à un cable défaillant. Maintenant le problème est résolu.
Voici une démonstration de notre machine (preque terminée) :
Jackpot avec les "7" avec un rendu de 20 jetons : <a href="https://www.youtube.com/watch?v=Jksg-hd5D3M">Machine avec jackpot '7'</a>
Jackpot avec les "ananas" avec un rendu de 5 jetons : <a href="https://www.youtube.com/watch?v=uL1TIpbR4S8">Machine avec jackpot 'ananas'</a>

Remarque : lorsqu'on branche notre alimentation à différents endroits, la rotation des roues est légèrement modifiée. Ce qui fait que dans les vidéos (prises à la maison), les trois symboles ne sont pas tout à fait alignés, alors qu'en salle de cours elle le sont très bien.

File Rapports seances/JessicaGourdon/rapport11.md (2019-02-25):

# Séance du 25 Février 2019
Durant les vacances, avec Julien, nous avons réalisé toutes les mesures et créés tous les schémas nécessaires pour l'impression de notre boite. 
Celle-ci fut prête aujourd'hui. Nous l'avons donc monté pour avoir le résultat suivant:

Durant les vacances, j'ai également travaillé sur un système de "tobogan" pour que les jetons du monnayeur soient bien guidés vers la sortie. Cela sera prêt d'ici peu.
<br/>
Pendant ce cours, nous avons également tenté de faire fonctionner correctement l'ensemble roue + monnayeur. Le programme utilisé est le suivant:
https://github.com/JessicaJulien/projet/blob/master/Codes/rouesMonnayeur.ino
<br/>
Cependant quelques problèmes ont été rencontrés.<br/>
Dans un premier temps, lorsqu'on connectait les 4 servomoteurs sur la carte, nos roues tournaient beaucoup trop longtemps. 
Pour remédier à ce problème nous avons mis un condensateur.<br/>
Puis, les valeurs utilisées pour le fonctionnement du monnayeur (les positions de 3 valeurs identiques) sont obsolètes puisqu'elles ont été mesurées avant certaines 
modifications des roues. Mais le véritable problème est que l'on ne parvient pas encore à contrôler de manière précise les positions des roues. 
Nous avons aujourd'hui réalisé des tests avec certaines valeurs mais il y avait certaines incohérences (une valeur qui renvoie deux positions différentes etc).

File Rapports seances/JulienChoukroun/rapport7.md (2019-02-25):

# Séance du 25 Février 2019

* Avec Jessica, nous sommes allés chercher notre boîte chez Castorama. Elle convient parfaitement. 
Boîte
* J'ai installé la lumière sur notre 3ème roue.
* Avec Jessica, on a travaillé sur l'ensemble roues + monnayeur. Le programme qu'on utilise est le suivant : https://github.com/JessicaJulien/projet/blob/master/Codes/rouesMonnayeur.ino
Du côté du monnayeur, la sortie des pièces fonctionne bien.
Mais on a eu quelques problèmes. Tout d'abord, lorsqu'on connectait tous les servomoteurs sur la carte Arduino (4 servomoteurs), nos roues tournaient trop longtemps et incorrectement. On a donc mis un condensateur. Au final, ce problème a été réglé.
Un autre problème est qu'on n'arrive pas encore à contrôler les positions des 3 roues en même temps, alors que séparément oui. On a donc commencé a tester "à la main" avec des valeurs arbitraires. Il faudra continuer.
* J'ai réalisé le programme de l'initialisation des 3 roues grâce au programme qui initialise une roue. Voici le programme : https://github.com/JessicaJulien/projet/blob/master/Codes/Initialisation3roues.ino

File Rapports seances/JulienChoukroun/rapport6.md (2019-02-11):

# Séance du 11 Février 2019

* On a eu un problème au niveau de la connexion des masses des 3 roues avec l'Arduino. C'est-à-dire, lorsque'on connectait les 3 masses à la planche à pain, les roues ne tournaient pas. Alors que lorsqu'on les connectait directement à la masse de l'Arduino, les roues tournaient. On est resté un bon bout de temps à essayer de résoudre ce problème. Finalement on a contourné le problème et on a connecté les masses des roues à celle de l'Arduino.
* Jessica a calculé les temps de rotation de chacune des roues pour connaître la position de tous les symboles.
Position des symboles
Grâce à cela, j'ai testé ces temps de rotation dans mon programme qui fait tourner les 3 roues. Par exemple, j'ai testé lorsqu'on a en sortie les 3 "7", ou lorsqu'on a en sortie les 3 "raisins". Voici les 2 démonstrations :

<a href="https://www.youtube.com/watch?v=Uk79yvcRZg8">Raisin-Raisin-Raisin</a>
Il reste quand même quelques réglages à faire.
* Enfin, on a crée la boite sur ordinateur. Il faudra aller prochainement au FabLab.

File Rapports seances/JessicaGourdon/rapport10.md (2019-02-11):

# Séance du 11 Février 2019
Avant la séance j'ai travaillé sur la création de suites de nombres correspondant à la position du centre de chaque autocollant. Pour cela je me suis servie du temps que met chaque roue à effectuer un tour.
J'ai donc réalisé des calculs pour associer chaque autocollant de chaque roue à un nombre. Le résultat est le suivant :

J'ai également réalisé un schéma final de l'intérieur de la machine à sous regroupant tous les éléments pour que nous puissions 
débuter la conception de la boite. Il s'agit du schéma suivant :
 <br/>
Aujourd'hui, dans un premier temps je me suis occupé de réaliser le code final pour le monnayeur c'est-à-dire le code nous renvoyant 
le bon nombre de jetons selon les figures obtenues. C'est le suivant :
https://github.com/JessicaJulien/projet/blob/master/Codes/monnayeurfin.ino <br/>
J'ai ensuite, grâce un logiciel, créé les croquis pour la conception de la boite. Les croquis sont comme ceci:
https://github.com/JessicaJulien/projet/blob/master/Documentation/box_510x300x750_3mm.svg  <br/>
Nous irons bientôt au Fablab pour finaliser la création de la boite.  <br/>
Enfin, nous avons eu un problème lorsque l'on a voulu tester le fonctionnement des troies roues ainsi que du monnayeur tous ensemble. 
Concernant les roues, il s'agissait d'un problème de masses que l'on a pu résoudre en les connectant directement à la carte et non pas à la planche. 
Concernant le monnayeur, celui-ci avait également cessé de fonctionner nous avons donc changé le moteur et effectué les réglages nécessaires pour que celui-ci fonctionne à nouveau correctement.

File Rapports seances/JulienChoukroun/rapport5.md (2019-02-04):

# Pendant les vacances de ski

* Pour éviter les frottements du capteur avec la roue, j'ai testé un nouveau capteur : le Keyes IR-01. C'est le capteur utilisé en cours pour la voiture qui suit une ligne noire.
Et ce capteur fonctionne très bien. Il n'y a plus aucun frottements. On va donc utilisé ce capteur. 
* J'ai donc adapté nos programmes déjà fait pour ce capteur.
Le nouveau programme pour l'initialisation est celui-ci : https://github.com/JessicaJulien/projet/blob/master/Codes/initialisationRoueNouveau.ino
Voici une démonstration : 
<a href="https://www.youtube.com/watch?v=4ydrxAV1xTY">Initialisation de la roue avec le nouveau capteur et la lumière</a>
Le nouveau programme qui contrôle la roue aléaroirement est celui-ci : https://github.com/JessicaJulien/projet/blob/master/Codes/controleRoueNouveau.ino
Voici une démonstration :
<a href="https://www.youtube.com/watch?v=9nWWDmIgQyY">Roue qui tourne de façon aléatoire avec le nouveau capteur et la lumière</a>
* Pour la lumière, on va utilisé une bande de led. J'ai donc programmé cette bande. Le programme est : https://github.com/JessicaJulien/projet/blob/master/Codes/lumiereBlanche.ino
Cela donne : 
Roue éclairée
* J'ai commencé la fixation des roues sur un support en bois. J'ai utilisé des pinces qui vont venir s'accrocher aux moteurs.
Support de fixation des roues

# Séance du 4 Février 2019

* J'ai fixé les 3 roues sur le support. J'ai scotché les moteurs sur les pinces avec du scotch double face pour bien maintenir les roues.
* J'ai rajouté les bandes de led sur les roues.
* J'ai crée un programme permettant de faire tourner les 3 roues en même temps de façon aléatoire en me servant du programme qui fait tourner une roue aléatoirement. Le code : https://github.com/JessicaJulien/projet/blob/master/Codes/3Roues.ino
Voici une démonstration :
<a href="https://www.youtube.com/watch?v=HAhRJ0OZeJ4">Les 3 roues</a>
Cela fonctionne bien. Il faudra tout de même faire quelques ajustements de hauteur de lumière et de symétrie des roues.

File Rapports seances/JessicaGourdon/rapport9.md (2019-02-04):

# Séance du 4 Février 2019
Initialement, nous voulions mettre un bras sur notre machine à sous, mais au vue des versions actuelles dans les casinos nous avons
pensé qu'il serait plus moderne de réaliser un système de bouton. Pour actionner les roues, il sera nécessaire d'insérer 
un jeton puis d'appuyer sur le bouton. Aujourd'hui, j'ai donc réaliser les tests d'un gros bouton poussoir avec une LED dans un premier temps.
Le code est celui-ci: https://github.com/JessicaJulien/projet/blob/master/Codes/bouton_projet.ino  <br/>
Une fois ce travail effectué je me suis occupée de la décoration des roues. J'ai donc collé chaque autocollant au bon emplacement sur celles-ci.
Les centres de chaque autocollant sont espacés un à un de 6,5 cm.

Nous avons eu également une idée concernant la rotation des roues. Après avoir fait tourner les roues 10 fois, au lieu de prendre un nombre aléatoire
décidant de la position finale de la roue, nous souhaitons créer une liste de nombres correspondant à la position du centre de chaque autocollant.
On tirera alors aléatoirement un nombre parmi cette liste pour décider de la position finale de chaque roue. Cela permettra d'éviter que la position finale se situe entre deux autocollants.
Je m'occuperai prochainement de créer cette liste de nombres.

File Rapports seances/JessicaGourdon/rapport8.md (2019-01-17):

# Séance du 17 Janvier 2019
Aujourd'hui avec Julien nous avions comme objectif de finaliser le système de rotation de la roue. 
Julien avait commencé à créer un programme pour cela. Il y a d'abord l'initialisation durant laquelle la roue tourne jusqu'au moment où le capteur atteint la fente.
Notre objectif était de faire tourner la roue pendant un certain nombre de secondes avant qu'elle se fige à une certaine position.
On déterminerait celle-ci grâce à un calcul prenant en compte le temps que la roue met pour faire un tour complet.
Julien avait donc mesuré ce temps. </br>
Aujourd'hui nous avons eu une idée qui simplifierait les choses. Il s'agit de faire tourner 10 fois la roue dans un premier temps. 
Grâce à la mesure du temps de Julien, il nous restait alors plus qu'à créer une boucle. Dans un deuxième temps, on tirerait un nombre aléatoire 
qui déciderait de la position finale de la roue (position adoptée pendant le onzième et dernier tour de roue). </br>
Nous avons rencontré plusieurs problèmes.
Tout d'abord, lors de chaque éxécution du programme la même série de nombres "aléatoires" étaient tirés.
Nous avons alors trouvé sur internet qu'utiliser la fonction randomSeed() résoudrait notre problème. Puis, nous avions un problème de vitesse.
En effet, pour réaliser un tour complet, notre roue met 390 ms. Mais pour lui faire réaliser 10 tours complets celle-ci mettra 460 ms par tour.
Nous pensons que cela est dû aux frottements exercés par le détecteur sur la roue.  </br>
Nous avons néanmoins réussi à finaliser ce système de rotation.
Le code est le suivant:  https://github.com/JessicaJulien/projet/blob/master/Codes/controleRoue.ino

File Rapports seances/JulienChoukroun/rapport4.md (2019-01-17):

# Avant cette séance

* Nous nous sommes rendu au FabLab de Sophia. Puis, de mon côté, j'ai assemblé la nouvelle roue. 
Vue de face :
Roue assemblée vue de face
Vue de l'intérieur :
Roue assemblée vue de l'intérieur
J'ai amélioré la rotation et l'initialisation de la roue car avec l'ancienne roue, on avait des frottements. Par exemple, entre le détecteur IR et le cercle ouvert situé derrière la roue. Voici une démonstration de l'initialisation avec la nouvelle roue : 
<a href="https://www.youtube.com/watch?v=ye7orix8uuc">Initialisation avec la nouvelle roue</a>
* J'ai commencé à réaliser le programme qui nous permettra de choisir la position de la roue. C'est-à-dire, après l'initialisation de la roue, on pourra la faire tourner de x secondes afin d'atteindre un certain symbole. Par exemple, pour atteindre le symbole "7", la roue doit faire pile un tour complet. Pour cela, j'ai calculé le temps que mettait la roue à faire un tour complet avec notre vitesse. Le code est le suivant : https://github.com/JessicaJulien/projet/blob/master/Codes/tourComplet.ino

# Séance du 17 Janvier 2019

* Avec Jessica, on a terminé le programme qui permet de choisir la position de la roue. On a rajouté la fonction random() qui permet de faire tourner la roue aléatoirement. Le programme est le suivant :
https://github.com/JessicaJulien/projet/blob/master/Codes/controleRoue.ino
Cependant, on avait un problème. A chaque éxécution de notre programme, on avait toujours la même série de nombre aléatoire qui sortait. Puis, on a trouvé sur internet comment résoudre ce problème : grâce à la fonction randomSeed(). Maintenant le problème est résolu.
On a aussi eu un autre problème. Pour faire un seul tour complet, notre roue met 390 ms. Mais lorsqu'on veut la faire tourner 10 fois, par exemple, on est obligé d'augmenter le temps de rotation à 460 ms. En effet, notre roue subit des frottements avec notre détecteur pendant les 10 rotations. Notre détecteur n'étant pas très stable, il est difficile de ne pas avoir de frottements même en limant la paroi.
Voici une démonstration du programme avec notre roue :
<a href="https://youtu.be/nJUigsxkim4">Roue qui tourne de façon aléatoire</a>
* A partir de maintenant on pourra assembler nos programmes, c'est-à-dire, les programmes de la roue et du monnayeur.

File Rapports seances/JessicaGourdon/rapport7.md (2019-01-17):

# Travail du week-end du 13 Janvier 2019

Durant ce week-end, je me suis donné pour objectif de finaliser le monnayeur. <br/>
Je devais d'abord fixer le cylindre en PVC tout en laissant un espace en dessous pour que chaque jeton puisse être éjecté. Pour cela j'ai utilisé deux équerres puisqu'avec une seule le cylindre ne tenait pas vraiment droit. <br/>
Puis je me suis servi d'une planche en bois auquel j'ai fixé le moteur d'un côté.
Cette planche en bois est elle-même surrélevée pour que le moteur ne s'abime pas. <br/>
J'ai également rallongé la pièce en bois servant à pousser les jetons. En effet, avec le morceau de bois initial les jetons restaient bloqués.
Je me suis donc servie d'une planche en plastique beaucoup plus longue et de forme arrondie pour qu'elle ne se bloque pas dans les équerres. L'avantage du plastique est que celui-ci est souple. Cela nous arrangeait ici puisque le morceau de bois initial n'était pas droit.
Ici, l'aile en plastique, se servira du socle du cylindre comme appuis pour pousser les jetons. Enfin, il a également été nécessaire d'ajuster la hauteur du socle du cylindre pour que l'aile en plastique puisse correctement éjecter les jetons. <br/>
Le résultat final ressemble à cela:

Le code final pour se servir du monnayeur est le suivant: 
https://github.com/JessicaJulien/projet/blob/master/Codes/monnayeur2.ino
Voivi une vidéo qui montre le fonctionnement de ce monnayeur : https://www.youtube.com/watch?v=uqmCoCaso7E&feature=youtu.be

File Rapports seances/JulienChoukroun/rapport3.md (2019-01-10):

# Pendant les vacances de Noël

* J'ai réaliser un programme qui fait tourner la roue pendant x secondes. Le code utilisé est le suivant :
https://github.com/JessicaJulien/projet/blob/master/Codes/actionneEtArreteRoue.ino
Voici une démonstration :
<a href="https://www.youtube.com/watch?v=P78dixj0G8c&feature=youtu.be">Roue qui tourne et s'arrête</a>
On voit que la roue possède une vitesse convenable. Nous avons donc le bon moteur.
* J'ai mis en place le détecteur IR sur la roue afin de détecter les différents symboles à l'aide d'encoches derrière la roue. 
roue avec détecteur IR
J'ai commencé par programmer l'initialisation de la roue. Cela va nous servir lorsqu'on va actionner le futur bras. A ce moment là, les roues vont tourner jusqu'à trouver une fente particulière, puis s'arrêter. Le code utilisé est le suivant :
https://github.com/JessicaJulien/projet/blob/master/Codes/initialisationRoue.ino 
Voici une démonstration : 
<a href="https://www.youtube.com/watch?v=aghbIHAVvek&feature=youtu.be">Initialisation de la roue à vitesse lente</a>
Ici, j'ai testé l'initialisation de la roue à vitesse lente car j'ai eu un problème. Notre roue n'est qu'un prototype réalisé à la main donc les découpes ne sont pas parfaites. Ainsi, le détecteur passe quelque fois dans des "vides" et donc arrête la roue alors qu'il y a pas de fentes. On va donc utiliser les découpeuses laser et imprimantes 3D, afin d'obtenir une roue parfaite.

* J'ai donc commencé à modéliser les pièces pour aller au FabLab de Sophia.

# Séance du 10 Janvier 2019

* J'ai d'abord fini de modéliser les pièces avec les bonnes dimensions finales. Voici toutes les pièces qu'on va découper/imprimer : 
https://github.com/JessicaJulien/projet/tree/master/Pieces
* J'ai participé à la mise en place du monnayeur avec un servomoteur à rotation 180° (fixation du servomoteur sur une petite planche de bois). Puis, on a réaliser le code qui va nous permettre de renvoyer les pièces gagnées. Le voici :
https://github.com/JessicaJulien/projet/blob/master/Codes/monnayeur1.ino
* J'ai réalisé un code qui permet de compter le nombre de fentes pendant que la roue tourne. Cela nous permettra de connaître la position de la roue. Voici le code :
https://github.com/JessicaJulien/projet/blob/master/Codes/compteFentes.ino 
Cependant, il n'est pas encore terminé car les tests avec le prototype sont quelques fois faussés.
* Nous avons revu le code de l'initialisation et sommes tombés sur un problème. Si on crée une fente pour chaque logo, on ne pourra plus initialiser la roue. On a donc eu l'idée d'agrandir uniquement la fente de l'initialisation, pour la différencier des autres fentes. Mais une nouvelle idée est venue. On créera une seule fente pour toute la roue, ainsi qu'un programme qui calculera la vitesse du servomoteur. On va alors obtenir le distance parcourue et donc la position de la roue.

* Juste après cette séance, on s'est rendu au FabLab de Sophia et avons découpé/imprimé les pièces modélisés. Je vais donc m'occuper du montage de la roue.

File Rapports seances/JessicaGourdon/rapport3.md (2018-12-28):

# Travail du 28 Décembre 2018
<strong> Elaboration du monnayeur </strong> <br/>
J'ai commencé à élaborer un mécanisme permettant de rendre les jetons en cas de victoire. Pour cela, j'ai réalisé un premier dessin.

Pour ce monnayeur, nous avons besoin d'un cylindre. L'utilisation de rouleaux de papiers toilette pour réaliser celui-ci pourrait être une idée.
Les jetons seraient alors empilés dans ce cylindre. En bas de celui-ci se trouve une ouverture à travers laquelle le dernier jeton se trouve, posé sur une plaque en bois.
On se servira d'un servomoteur auquel est fixé une plaque en bois pour pousser chaque jeton un par un dans le bac. Ainsi, nous sommes en mesure de contrôler le nombre de jetons rendus.

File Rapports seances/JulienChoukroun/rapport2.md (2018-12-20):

# Séance du 20 Décembre 2018

* Test du détecteur HC-SR04 qui permet de détecter le passage du futur levier, permettant ainsi le démarrage des roues.
Le code utilisé est le suivant : 
https://github.com/JessicaJulien/projet/blob/master/Codes/detectionLevier.ino
détecte le passage du levier
* Au vue de la semaine précédente, le professeur nous a conseillé d'utiliser un servomoteur à rotation continue. On a donc réaliser des tests de vitesses. Tests concluants puisque la roue tourne à une bonne vitesse.
Le code utlisé est le suivant : 
https://github.com/JessicaJulien/projet/blob/master/Codes/premierProgrammeServomoteurRotationContinue.ino
* On a remplacé la bande de papier de la semaine dernière par une bande platique plus large et plus solide.
roue avec servomoteur et bande plastique
* En attendant de recevoir les autocollants pour la roue, on va mettre en place le détecteur IR sur la roue afin de détecter les différents symboles à l'aide d'encoches derrière la roue.

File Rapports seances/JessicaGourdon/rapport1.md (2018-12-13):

# Séance du 13 Décembre 2018

<strong> Création du github </strong> <br/>
Lors de cette première séance, nous avons commencé par créer le github et nous nous sommes familiarisés avec cette plateforme.

<strong> Plannification du projet </strong> <br/>
Pour commencer notre projet, nous avons listé les différentes tâches que l'on avait à faire ainsi que le matériel nécessaire pour réaliser chacune d'elles. Cela nous a permis de prendre nos marques et de pouvoir plannifier correctement notre travail. A partir de cette liste, nous allons réaliser notre diagramme de Gantt.
liste et planification part1
liste et planification part2

<strong> Premier test du moteur pas à pas </strong> <br/>
Lors de ce premier essai du moteur pas à pas, nous nous sommes servis d'une roue en bois et notre but était de savoir si ce moteur permettait à la roue de tourner aussi vite que nous l'attendions. Finalement, la roue tourne trop lentement. Nous allons donc chercher un autre moteur permettant à la roue d'avoir une vitesse plus élevée.
test roue en bois

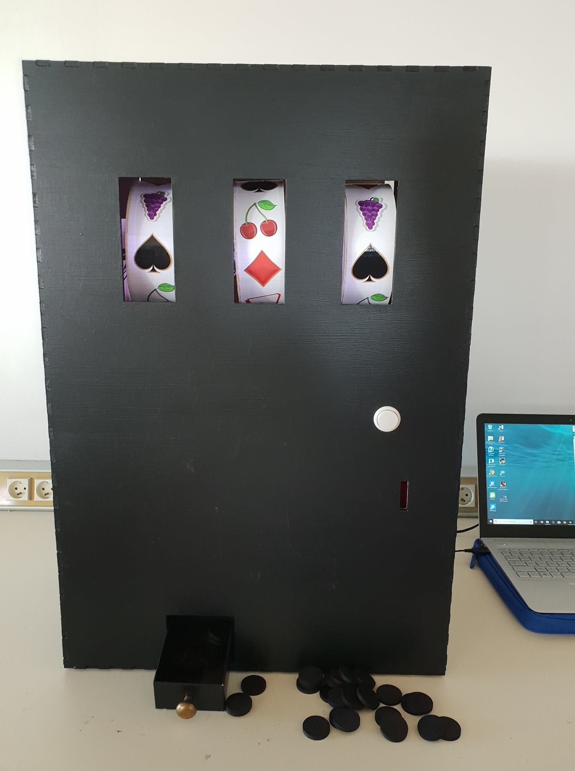
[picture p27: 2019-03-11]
Documentation/Boîte-Machine/machineASous3.jpg

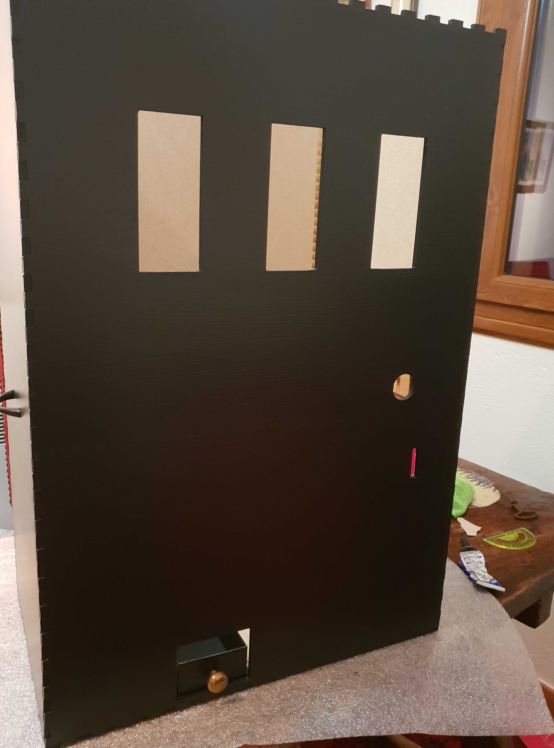
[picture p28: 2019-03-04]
Documentation/Boîte-Machine/tiroir.jpg

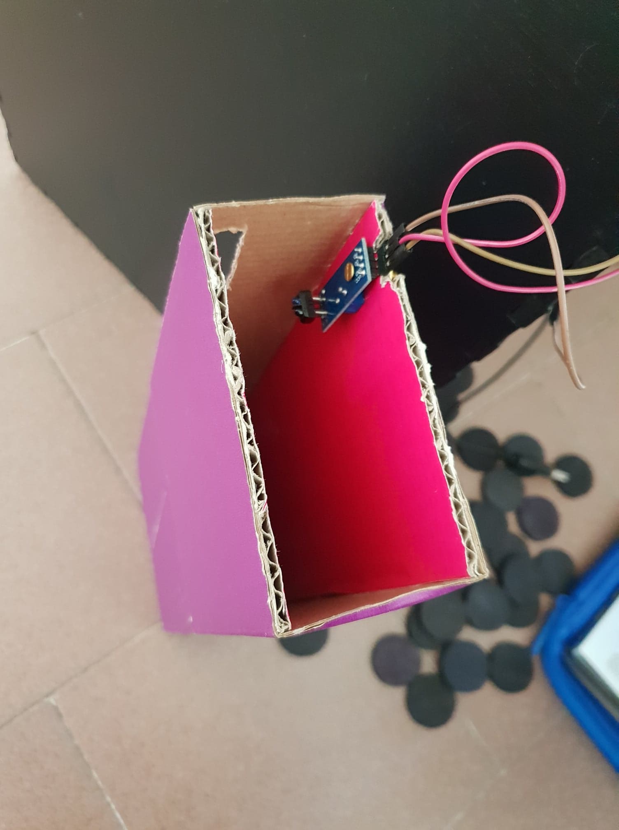
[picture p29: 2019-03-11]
Documentation/InsertionJeton/insertionJeton.jpg

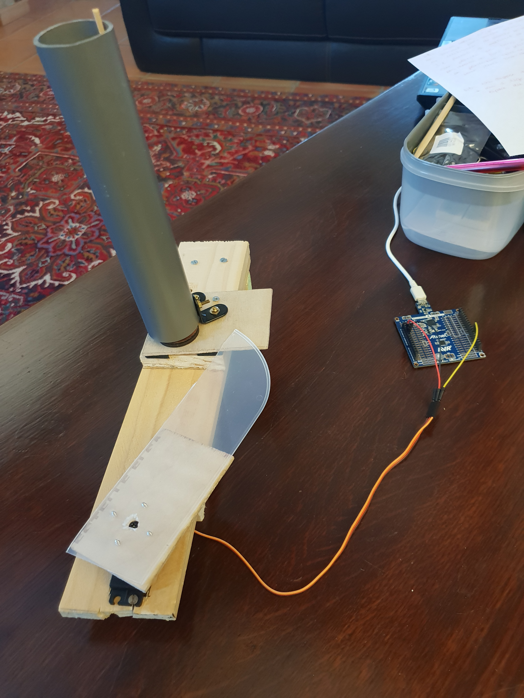
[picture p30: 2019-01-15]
Documentation/Monnayeur/monnayeur.jpg

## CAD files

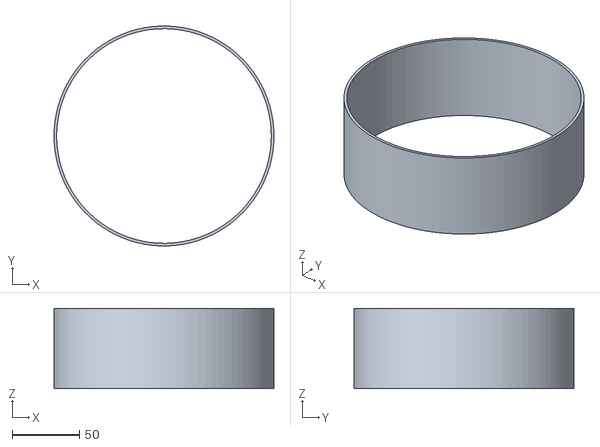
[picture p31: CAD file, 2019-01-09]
Pieces/contourCylindreOuvert.stl
164.0 x 163.9 x 60.0

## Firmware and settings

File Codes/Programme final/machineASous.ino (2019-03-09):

/** Projet Arduino : machine à sous

* Auteur : Julien Choukroun et Jessica Gourdon

* Ce programme fait fonctionner notre machine à sous.
* Le principe est d'insérer une pièce. A ce moment là, les roues vont se mettre à une position initiale.
* Puis on appuie sur le bonton. Les roues vont tourner et s'arrêter aléatoirement.
* Pour gagner, il faut aligner 3 symboles identiques.
* Si on a gagné, le monnayeur nous donne des pièces. Sinon le monnayeur nous rend rien.
* Dans notre programme, on a aussi inséré un système de lumière, de musique et de bluetooth.
*/


// Bluetooth
#include <SoftwareSerial.h>
#define RX 12
#define TX 13
SoftwareSerial BlueT(RX,TX);

// Servomoteur1
#include <Servo.h>
Servo servo1;

// Servomoteur2
Servo servo2;

// Servomoteur3
Servo servo3;

// Servomoteur4 monnayeur
Servo servo4;

// Détecteur des 3 roues
const int detecteur1 = 4;
const int detecteur2 = 7;
const int detecteur3 = 9;

// Etat des 3 détecteurs sur les roues
int Etat1 = 0;
int Etat2 = 0;
int Etat3 = 0;

int i = 0;
int k = 0;
int l = 0;

// Nombres aléatoires
int nbAleatoire1 = 0;
int nbAleatoire2 = 0;
int nbAleatoire3 = 0;

int nbrand1;
int nbrand2;
int nbrand3;

// Monnayeur
int m = 0;
int jeton = 0;

// Bouton
const int bouton = 10;
int val = 0;

// Détecteur de pièce
const int detecteurPiece = 11;
int EtatPiece = 0;

int variable1 = 0;
int variable2 = 0;
int variable3 = 0;


// Lumière
#include <Adafruit_NeoPixel.h>
#define PIXEL_PIN 5 // On définit le pin où est connecté la patte DATA du bandeau
#define PIXEL_COUNT 3 // On définit le nombre de LED compris sur le Ruban de LED

//   NEO_KHZ800  800 KHz bitstream (most NeoPixel products w/WS2812 LEDs)
//   NEO_KHZ400  400 KHz (classic 'v1' (not v2) FLORA pixels, WS2811 drivers)
//   NEO_GRB     Pixels are wired for GRB bitstream (most NeoPixel products)
//   NEO_RGB     Pixels are wired for RGB bitstream (v1 FLORA pixels, not v2)

Adafruit_NeoPixel strip = Adafruit_NeoPixel(PIXEL_COUNT, PIXEL_PIN, NEO_GRB + NEO_KHZ800); // Paramètre l'objet strip qui correspond à toute les LED du ruban


// Musique
#define ARDUINO_RX 15//should connect to TX of the Serial MP3 Player module 
#define ARDUINO_TX 14//connect to RX of the module 
SoftwareSerial mySerial(ARDUINO_RX, ARDUINO_TX);//init the serial protocol, tell to myserial wich pins are TX and RX 
char data="A";
//////////////////////////////////////////////////////////////////////////////////// 
//all the commands needed in the datasheet(http://geekmatic.in.ua/pdf/Catalex_MP3_board.pdf) 
static int8_t Send_buf[8] = {0} ;//The MP3 player undestands orders in a 8 int string 
                                //0X7E FF 06 command 00 00 00 EF;(if command =01 next song order)  
#define NEXT_SONG 0X01  
#define PREV_SONG 0X02  
#define CMD_PLAY_W_INDEX 0X03 //DATA IS REQUIRED (number of song) 
#define VOLUME_UP_ONE 0X04 
#define VOLUME_DOWN_ONE 0X05 
#define CMD_SET_VOLUME 0X06//DATA IS REQUIRED (number of volume from 0 up to 30(0x1E)) 
#define SET_DAC 0X17 
#define CMD_PLAY_WITHVOLUME 0X22 //data is needed  0x7E 06 22 00 xx yy EF;(xx volume)(yy number of song) 
#define CMD_SEL_DEV 0X09 //SELECT STORAGE DEVICE, DATA IS REQUIRED 
#define DEV_TF 0X02 //HELLO,IM THE DATA REQUIRED 
#define SLEEP_MODE_START 0X0A 
#define SLEEP_MODE_WAKEUP 0X0B 
#define CMD_RESET 0X0C//CHIP RESET 
#define CMD_PLAY 0X0D //RESUME PLAYBACK 
#define CMD_PAUSE 0X0E //PLAYBACK IS PAUSED 
#define CMD_PLAY_WITHFOLDER 0X0F//DATA IS NEEDED, 0x7E 06 0F 00 01 02 EF;(play the song with the directory \01\002xxxxxx.mp3 
#define STOP_PLAY 0X16 
#define PLAY_FOLDER 0X17// data is needed 0x7E 06 17 00 01 XX EF;(play the 01 folder)(value xx we dont care) 
#define SET_CYCLEPLAY 0X19//data is needed 00 start; 01 close 
#define SET_DAC 0X17//data is needed 00 start DAC OUTPUT;01 DAC no output 
//////////////////////////////////////////////////////////////////////////////////// 

void sendCommand(int8_t command, int16_t dat) { 
delay(20); 
Send_buf[0] = 0x7e; //starting byte 
Send_buf[1] = 0xff; //version 
Send_buf[2] = 0x06; //the number of bytes of the command without starting byte and ending byte 
Send_buf[3] = command; // 
Send_buf[4] = 0x00;//0x00 = no feedback, 0x01 = feedback 
Send_buf[5] = (int8_t)(dat >> 8);//datah 
Send_buf[6] = (int8_t)(dat); //datal 
Send_buf[7] = 0xef; //ending byte 
for(uint8_t i=0; i<8; i++){ 
  mySerial.write(Send_buf[i]) ; 
} 
} 


void setup() {
  
  Serial.begin(9600);
  
  // Bluetooth
  BlueT.begin(9600);
  
  // Servomoteurs
  servo1.attach(3);
  servo1.writeMicroseconds(1525); // Ne tourne pas
  
  servo2.attach(6);
  servo2.writeMicroseconds(1525); // Ne tourne pas
  
  servo3.attach(8);
  servo3.writeMicroseconds(1537); // Ne tourne pas
  

  // Détecteurs sur les roues
  pinMode(detecteur1, INPUT);
  pinMode(detecteur2, INPUT);
  pinMode(detecteur3, INPUT);

  randomSeed(analogRead(0)); // Permet de générer différents numéros de départ à chaque exécution du programme.
  
  // Lumière
  strip.begin(); // Lance la connection
  strip.show(); // Initialise toute les led à 'off'
  
  
  // Monnayeur
  servo4.attach(2);
  servo4.writeMicroseconds(1760); // Position initiale
  
  // Bouton
  pinMode(bouton,INPUT);

  // Détecteur de pièce
  pinMode(detecteurPiece,INPUT);

  // Musique
  mySerial.begin(9600);//Start our Serial coms for our serial monitor! 
  delay(500);//Wait chip initialization is complete 
  sendCommand(CMD_SEL_DEV, DEV_TF);//select the TF card   
  delay(200);//wait for 200ms 
  
}

// Fonction qui allume les bandes de led en blanc
void lumiere() {
  
  strip.setBrightness(100); // Règle la luminosité à 100 % de la luminosité maximale
  for(int i = 0 ; i < 3 ; i++){ // Ici, on a i < 3 car on utilise 3 led
    strip.setPixelColor(i, 255, 255, 255); // 255 pour la lumière blanche
  }
  strip.show(); // On affiche 
  delay(100);
  
}

void loop() {

  // Allume les leds
  lumiere();

  // Etat de tous les détecteurs Keyes-01
  Etat1 = digitalRead(detecteur1);
  Etat2 = digitalRead(detecteur2);
  Etat3 = digitalRead(detecteur3);
  EtatPiece = digitalRead(detecteurPiece);

  //Détecteur de piece
  if (EtatPiece == 1) { // Si on passe une pièce devant ce détecteur alors initialise les 3 variables suivantes à 1
    variable1 = 1;
    variable2 = 1;
    variable3 = 1;
    delay(10);
  }

  // Initialisation
  // On place les roues à une position initiale qui est "7-7-7" en sortie
  if (variable1 == 1 || variable2 == 1 || variable3 == 1){ // Si on a passé une pièce devant le détecteur
    
    servo1.writeMicroseconds(1510); // La première roue se met à touner à vitesse lente
    if (Etat1 == 1) {
      servo1.writeMicroseconds(1525); // Si le détecteur rencontre la bande noire, la roue s'arrête
      variable1 = 0;
    }
    
    servo2.writeMicroseconds(1510); // La deuxième roue se met à touner à vitesse lente
    if (Etat2 == 1) {
      servo2.writeMicroseconds(1525); // Si le détecteur rencontre la bande noire, la roue s'arrête
      variable2 = 0;
    }
    
    servo3.writeMicroseconds(1525); // La troisième roue se met à touner à vitesse lente
    if (Etat3 == 1) {
      servo3.writeMicroseconds(1537); // Si le détecteur rencontre la bande noire, la roue s'arrête
      variable3 = 0;
    }
    
    delay(50);
  }
  
  // Bouton
  val = digitalRead(bouton);
  if (val == LOW){ // Si on appuie sur le bouton, les roues tournent
    
    // Musique d'ambiance
    sendCommand(CMD_PLAY_WITHFOLDER, 0X0F00101);
  
    // Le jeu commence
  
    servo1.writeMicroseconds(1485);
    delay(1500);
    servo2.writeMicroseconds(1492);
    servo3.writeMicroseconds(1500);
    delay(600);
  
    for (k = 0 ; k <= 5 ; k++){ // Les roues tournent environ 10 secondes
    
      for(i = 0 ; i < 39; i++){ // La 1ère roue fait un tour en 390 ms
        servo1.writeMicroseconds(1300); // La roue tourne à vitesse normale
        delay(10);
      }
      for(i = 0 ; i < 38 ; i++){ // La 2ème roue fait un tour en 380 ms
        servo2.writeMicroseconds(1300); // La roue tourne à vitesse normale
        delay(10);
      }
      for(i = 0 ; i < 39 ; i++){ // La 3ème roue fait un tour en 390 ms
        servo3.writeMicroseconds(1300); // La roue tourne à vitesse normale
        delay(10);
      }
    }

    // C'est ici que l'aléatoire entre en jeu
    // Sélection d'un nombre aléatoire
    // Grâce à ce nombre, les roues feront un dernier tour et s'arrêteront aléatoirement
    nbrand1 = random(30,46);
    while ((nbrand1 == 31)||(nbrand1 == 33)||(nbrand1 == 34)||(nbrand1 == 35)||(nbrand1 == 36)||(nbrand1 == 41)||(nbrand1 == 42)||(nbrand1 == 43)){
      nbrand1 = random(30,46);
    }
    nbrand2 = random(29,45);
    while ((nbrand2 == 30)||(nbrand2 == 32)||(nbrand2 == 33)||(nbrand2 == 34)||(nbrand2 == 35)||(nbrand2 == 40)||(nbrand2 == 41)||(nbrand2 == 42)){
      nbrand2 = random(29,46);
    }
    nbrand3 = random(30,46);
    while ((nbrand3 == 31)||(nbrand3 == 33)||(nbrand3 == 34)||(nbrand3 == 35)||(nbrand3 == 36)||(nbrand3 == 41)||(nbrand3 == 42)||(nbrand3 == 43)){
      nbrand3 = random(30,46);
    }
   
    // Tour aléatoire de la 1ère roue
    nbAleatoire1 = nbrand1;
    for (l = 0 ; l < nbAleatoire1 ; l++){ 
      servo1.writeMicroseconds(1300);
      delay(10);
    }
    // Tour aléatoire de la 2ème roue
    nbAleatoire2 = nbrand2;
    for (l = 0 ; l < nbAleatoire2 ; l++){ 
      servo2.writeMicroseconds(1300);
      delay(10);
    }
    // Tour aléatoire de la 3ème roue
    nbAleatoire3 = nbrand3;
    for (l = 0 ; l < nbAleatoire3 ; l++){ 
      servo3.writeMicroseconds(1300);
      delay(10);
    }

    // Affichage des nombres aléatoires pour tester si cela fonctionne bien (optionnel)
    Serial.println(nbAleatoire1);
    Serial.println(nbAleatoire2);
    Serial.println(nbAleatoire3);

    // Arrête les roues
    servo1.detach(); 
    servo2.detach();
    servo3.detach();
 

    // Monnayeur et Bluetooth

    // Cas où on tombe sur trois 7
    if ((nbAleatoire1 == 39)&&(nbAleatoire2 == 38)&&(nbAleatoire3 == 39)){
      jeton = 20;
      // Bluetooth
      BlueT.print("*A" + String("Bravo ! Vous avez gagne 20 jetons !") + "*");
      // Musique de gros jackpot
      sendCommand(CMD_PLAY_WITHFOLDER, 0X0F00103);
    }
  
    // Cas où on tombe sur trois trèfles ou trois coeurs ou trois piques ou trois carreaux
    else if (((nbAleatoire1 == 45)&&(nbAleatoire2 == 44)&&(nbAleatoire3 == 45)) || ((nbAleatoire1 == 40)&&(nbAleatoire2 == 39)&&(nbAleatoire3 == 40)) || ((nbAleatoire1 == 38)&&(nbAleatoire2 == 37)&&(nbAleatoire3 == 38)) || ((nbAleatoire1 == 30)&&(nbAleatoire2 == 29)&&(nbAleatoire3 == 30))) {
      jeton = 10;
      // Bluetooth
      BlueT.print("*A" + String("Bravo ! Vous avez gagne 10 jetons !") + "*");
      // Musique de petit jackpot
      sendCommand(CMD_PLAY_WITHFOLDER, 0X0F00102);
    }
  
    // Cas où on tombe sur trois ananas ou trois raisin ou trois cerises
    else if (((nbAleatoire1 == 37)&&(nbAleatoire2 == 36)&&(nbAleatoire3 == 37)) || ((nbAleatoire1 == 32)&&(nbAleatoire2 == 31)&&(nbAleatoire3 == 32)) || ((nbAleatoire1 == 44) && (nbAleatoire2 == 43) && (nbAleatoire3 == 44))) {
      jeton = 5;
      // Bluetooth
      BlueT.print("*A" + String("Bravo ! Vous avez gagne 5 jetons !") + "*");
      // Musique de petit jackpot
      sendCommand(CMD_PLAY_WITHFOLDER, 0X0F00102);
    }

    // Cas où aucun des 3 symboles ne sont alignés
    else {
      // Bluetooth
      BlueT.print("*A" + String("Perdu ! Vous n'avez rien gagne !") + "*");
      // Musique de perdant
      sendCommand(CMD_PLAY_WITHFOLDER, 0X0F00104);
    }

    // Rendu du monnayeur
    for (m = 0 ; m < jeton ; m++){ 
      servo4.writeMicroseconds(2050); // Pousse le jeton
      delay(700);
      servo4.writeMicroseconds(1760); // Revient à sa position initiale
      delay(700); 
    }
  
    // Arrête le monnayeur
    servo4.detach();
  
  }
  
}

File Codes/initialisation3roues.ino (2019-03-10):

// Programme qui initialise les roues. 
// Les roues vont tourner à vitesse lente jusqu'à trouver la fente noire. A ce moment là, elles s'arrêteront.

#include <Servo.h>
// Servomoteur1
Servo servo1;

// Servomoteur2
Servo servo2;

// Servomoteur3
Servo servo3;

const int detecteur1 = 4;
const int detecteur2 = 7;
const int detecteur3 = 9;

int Etat1 = 0;
int Etat2 = 0;
int Etat3 = 0;

void setup() {
  
  Serial.begin(9600);
  
  // Servomoteurs
  servo1.attach(3);
  servo2.attach(6);
  servo3.attach(8);
  
  // Détecteurs
  pinMode(detecteur1, INPUT);
  pinMode(detecteur2, INPUT);
  pinMode(detecteur3, INPUT);

}

void loop() {
  
  Etat1 = digitalRead(detecteur1);
  Etat2 = digitalRead(detecteur2);
  Etat3 = digitalRead(detecteur3);
  
  // Servo1
  servo1.writeMicroseconds(1510); // La première roue se met à touner à vitesse lente
  if (Etat1 == 1) {
    servo1.writeMicroseconds(1526); // Si le détecteur rencontre la bande noire, la roue s'arrête
  }
  
  // Servo2
  servo2.writeMicroseconds(1508); // La deuxième roue se met à touner à vitesse lente
  if (Etat2 == 1) {
    servo2.writeMicroseconds(1525); // Si le détecteur rencontre la bande noire, la roue s'arrête
  }

  // Servo3
  servo3.writeMicroseconds(1525); // La troisième roue se met à touner à vitesse lente
  if (Etat3 == 1) {
    servo3.writeMicroseconds(1537); // Si le détecteur rencontre la bande noire, la roue s'arrête
  }
  
  delay(100);
  
}
